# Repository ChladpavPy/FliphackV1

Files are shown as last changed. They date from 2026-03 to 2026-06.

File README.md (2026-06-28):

# Fliphack V1

A custom, pocket sized hardware multitool inspired by the Flipper Zero. Built to learn custom PCB design and integrate specific modules like GPS and long-range RF, including also the other Filpper Zero modules. Designed entirely from scratch in KiCad and Fusion 360.

## Project Features

* **Microcontroller:** ESP32-S3 WROOM 1U (16MB Flash, 8MB PSRAM) with external wifi antena
* **Display:** 1.69" IPS TFT LCD (ST7789 SPI)
* **Wireless and RF:** Sub-GHz (CC1101), 2.4GHz (nRF24L01+PA+LNA), NFC/RFID (PN532), and also external WIFI antena
* **Navigation:** GPS (NEO-8M)
* **Storage:** MicroSD Card module for SD card
* **Infrared:** High-power IR Transmitter (Vishay TSAL6400) and 38kHz IR Receiver
* **Controls:** 5-way navigation switch + SMT tactile buttons for BOOT and RST
* **Power:** External battery - 3.7V 800mAh, Size: 802540 (8x25x40mm) and USB C interface
* **Case:** Custom 3D modeled thick enclosure with snap-fit parts and M3 inserts

## Gallery

### Build Preview
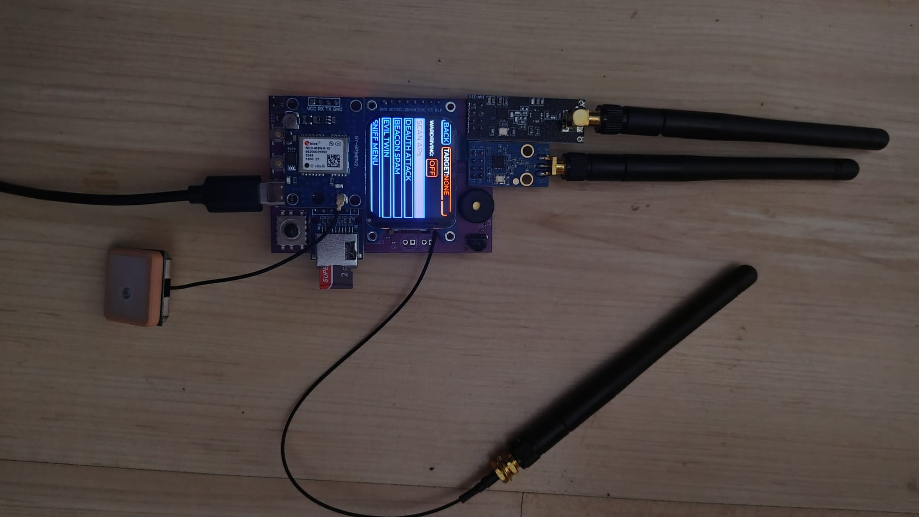
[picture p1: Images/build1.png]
Build Preview


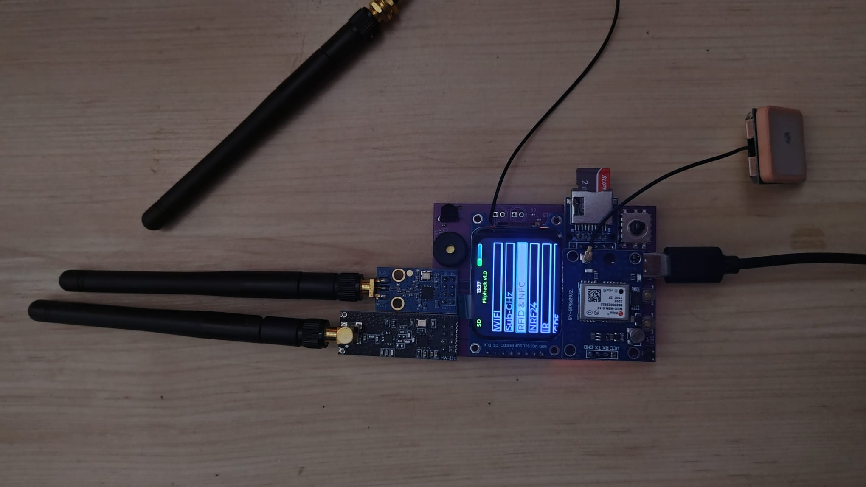
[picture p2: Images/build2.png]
Build Preview


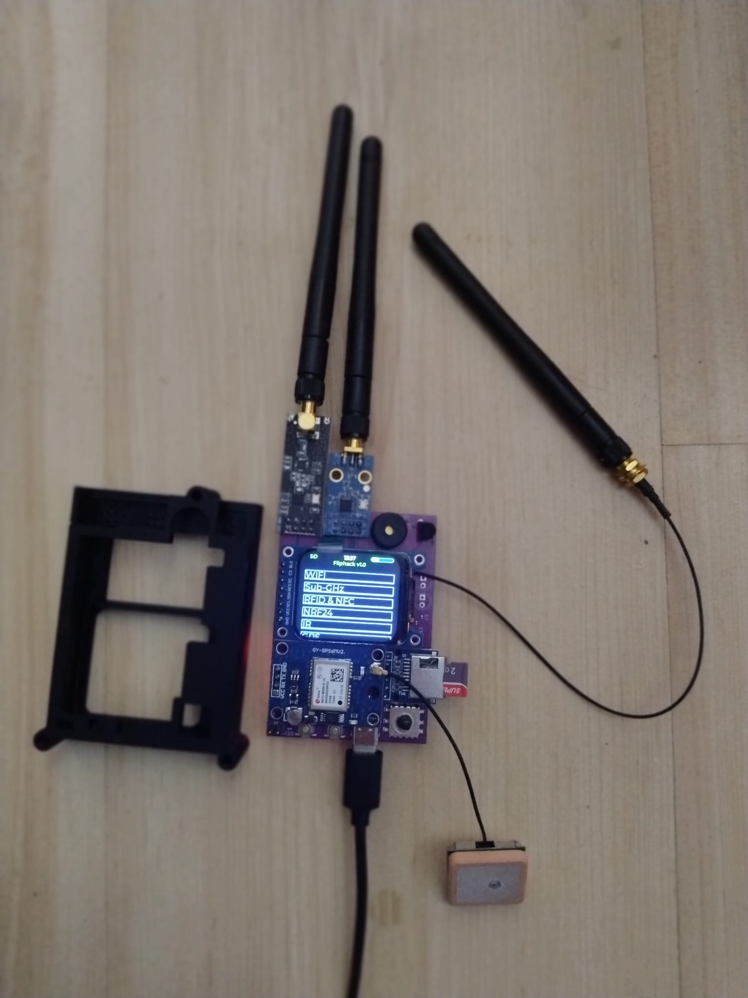
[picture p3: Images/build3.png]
Build Preview


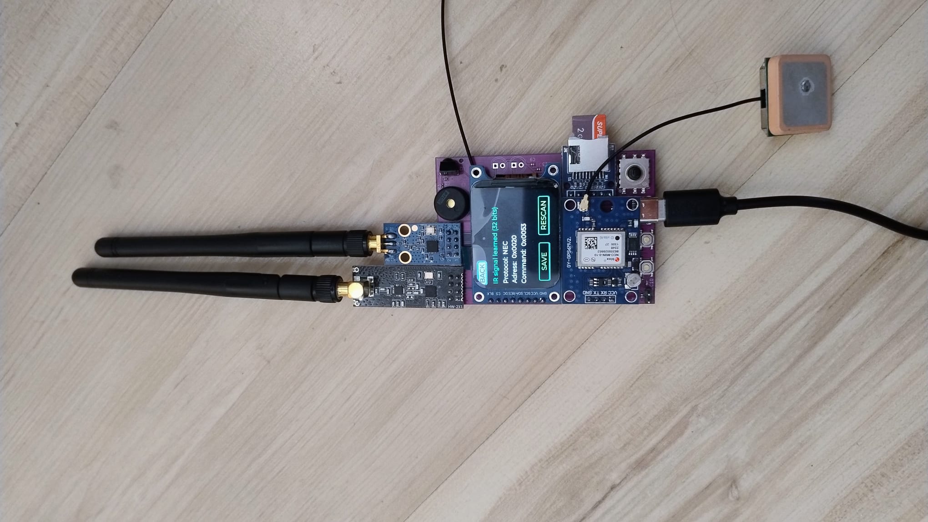
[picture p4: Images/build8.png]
Build Preview


### Assembly Preview
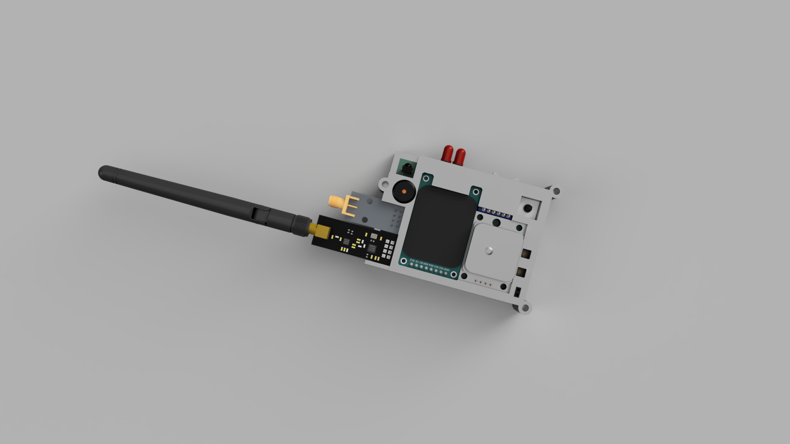
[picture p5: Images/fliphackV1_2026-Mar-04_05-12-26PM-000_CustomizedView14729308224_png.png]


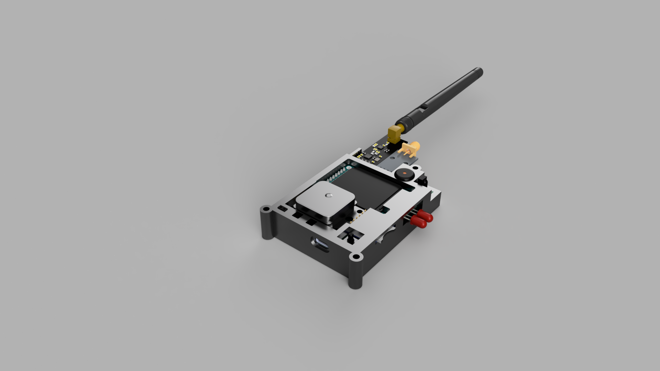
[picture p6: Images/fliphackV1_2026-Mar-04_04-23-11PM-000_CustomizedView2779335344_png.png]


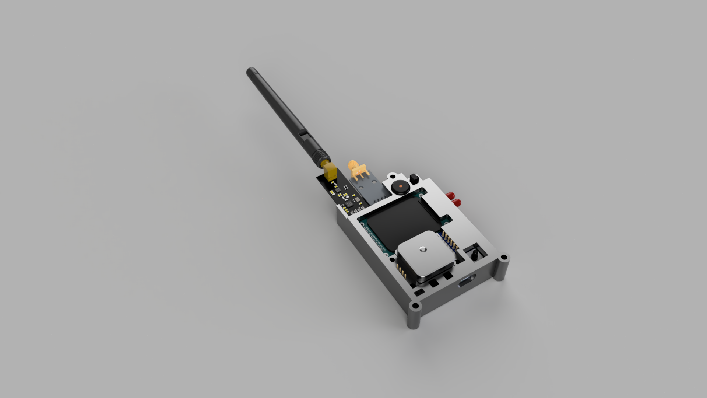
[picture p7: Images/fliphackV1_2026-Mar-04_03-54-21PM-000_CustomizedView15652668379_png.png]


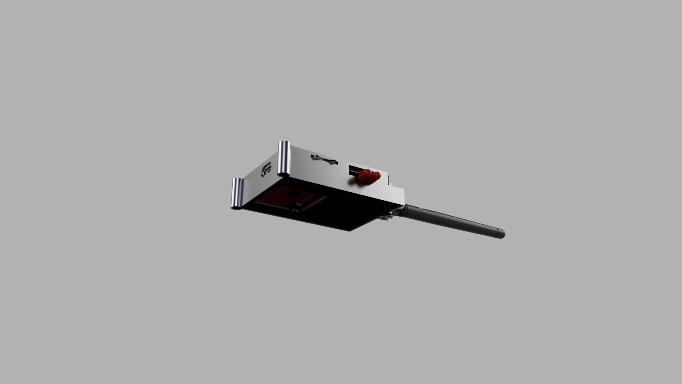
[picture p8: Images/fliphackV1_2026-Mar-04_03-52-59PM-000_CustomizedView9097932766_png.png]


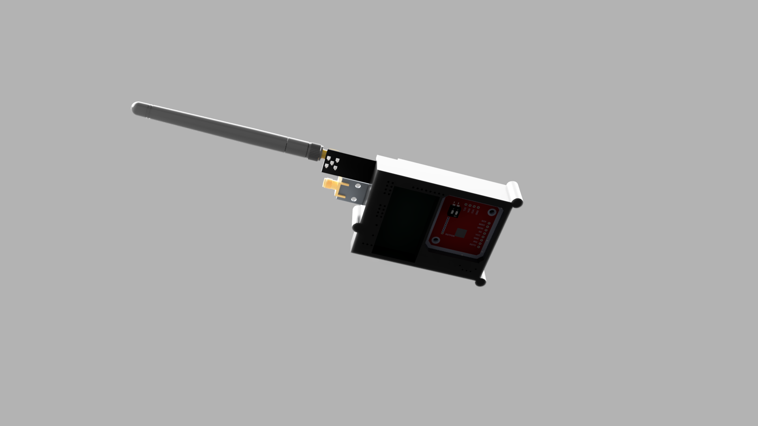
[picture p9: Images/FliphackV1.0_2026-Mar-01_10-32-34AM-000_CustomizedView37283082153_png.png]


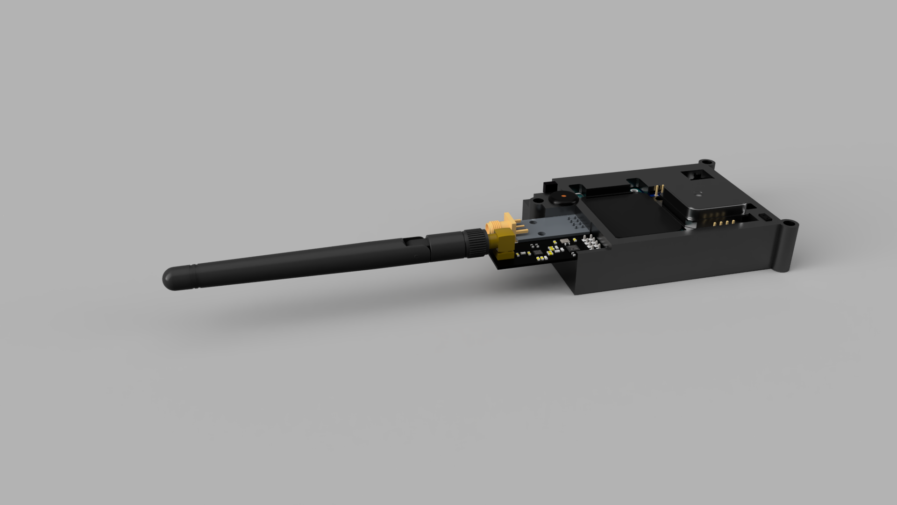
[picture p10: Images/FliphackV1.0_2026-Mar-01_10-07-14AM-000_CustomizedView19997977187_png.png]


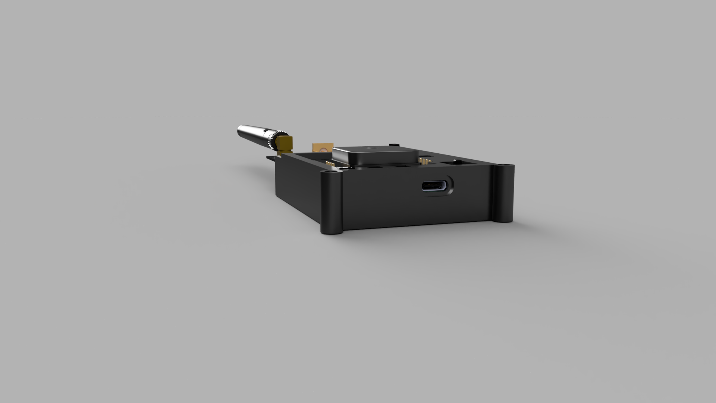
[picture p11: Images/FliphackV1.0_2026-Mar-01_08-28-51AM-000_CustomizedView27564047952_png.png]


### 3D PCB Render
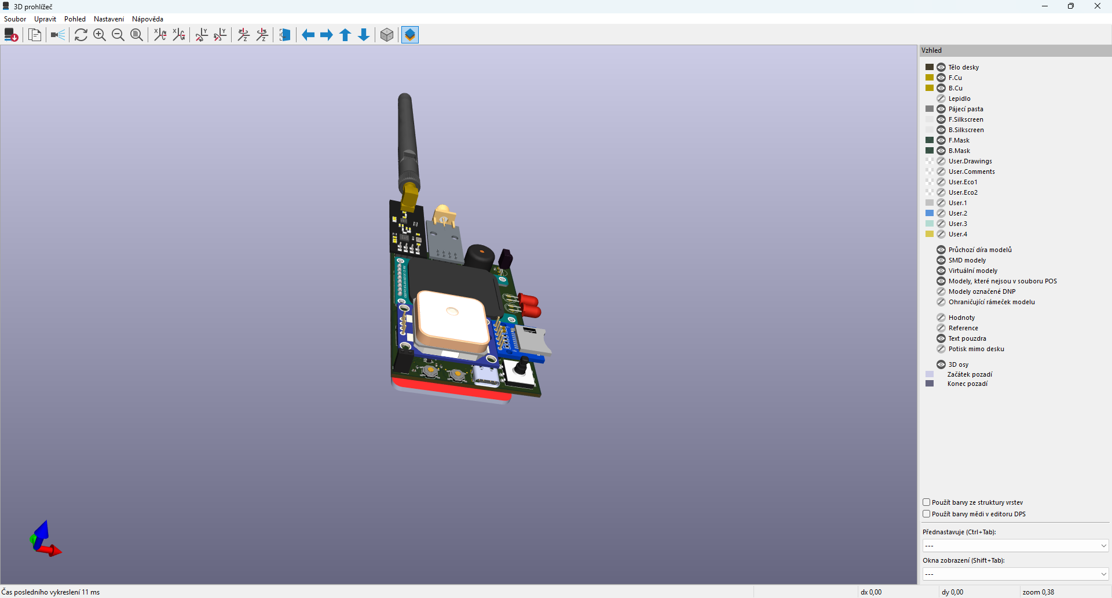
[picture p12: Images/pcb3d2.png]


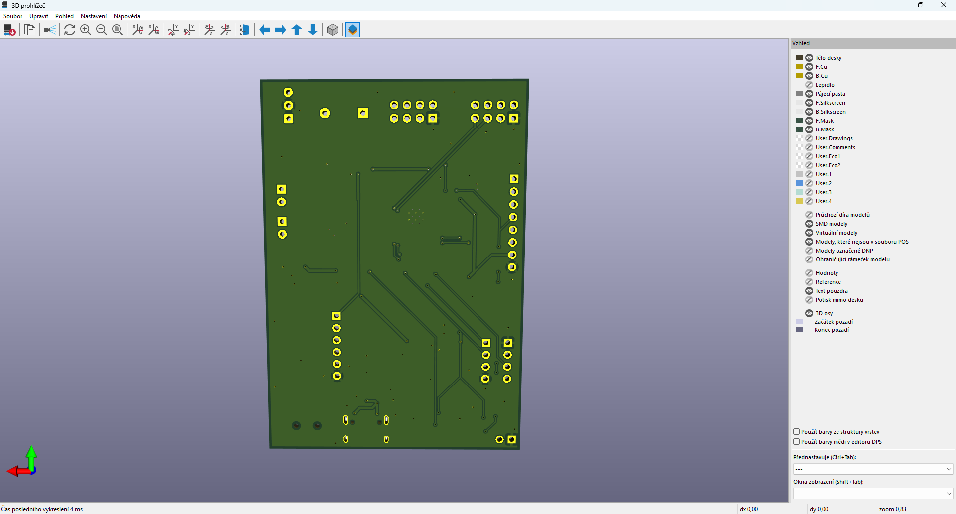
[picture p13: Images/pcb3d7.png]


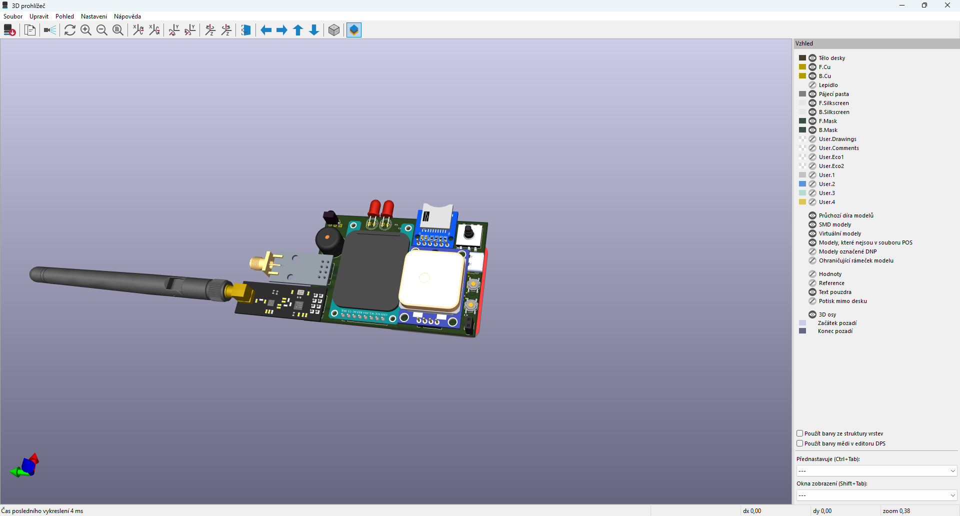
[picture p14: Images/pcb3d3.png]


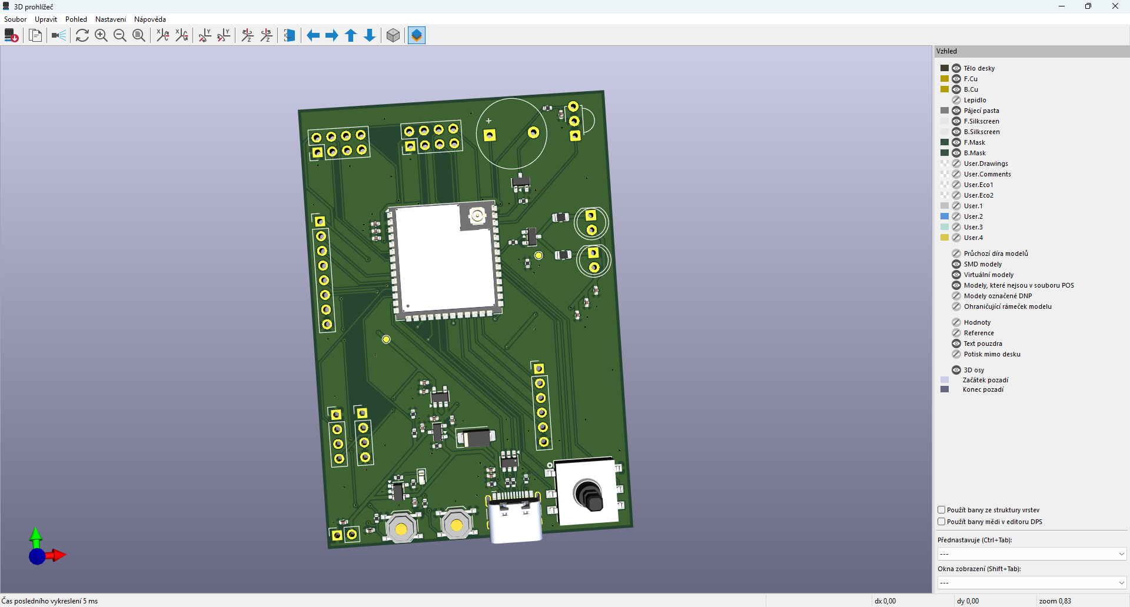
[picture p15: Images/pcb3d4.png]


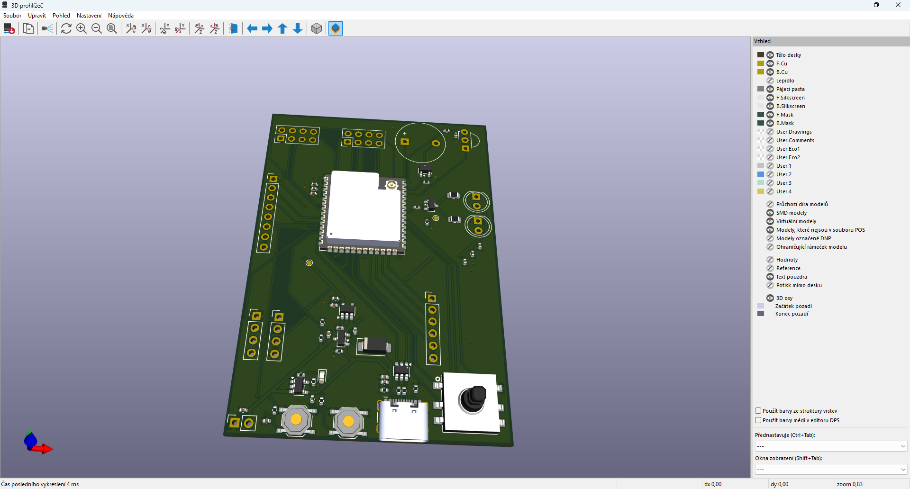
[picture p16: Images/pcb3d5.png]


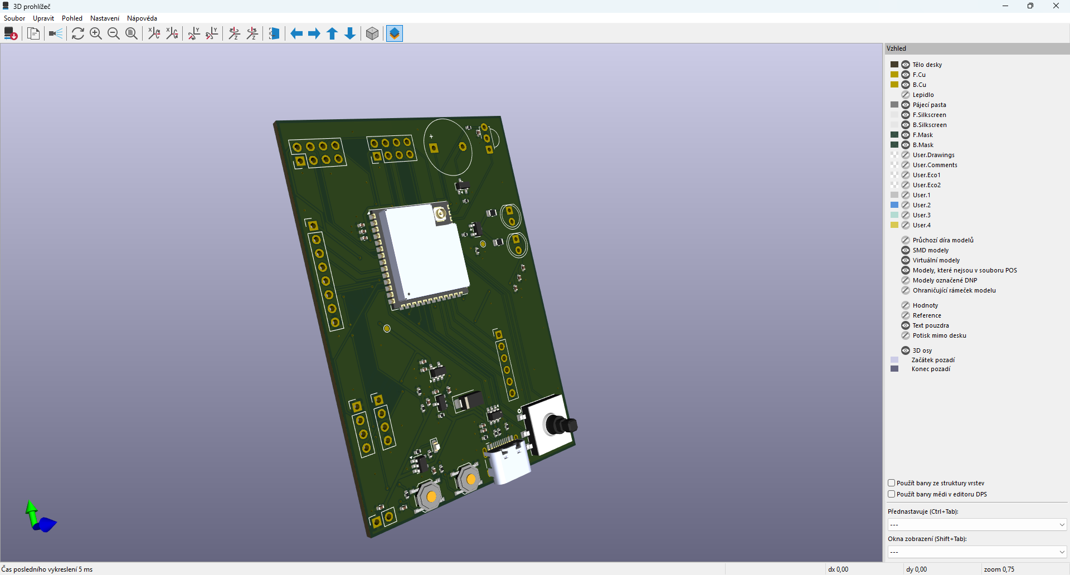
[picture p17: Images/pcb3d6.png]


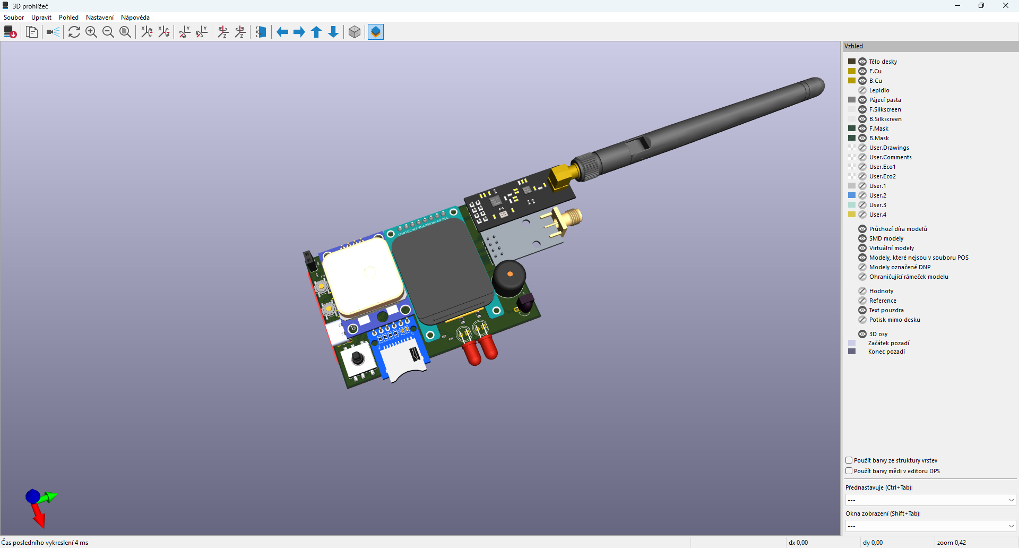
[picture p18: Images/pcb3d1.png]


### PCB Routing
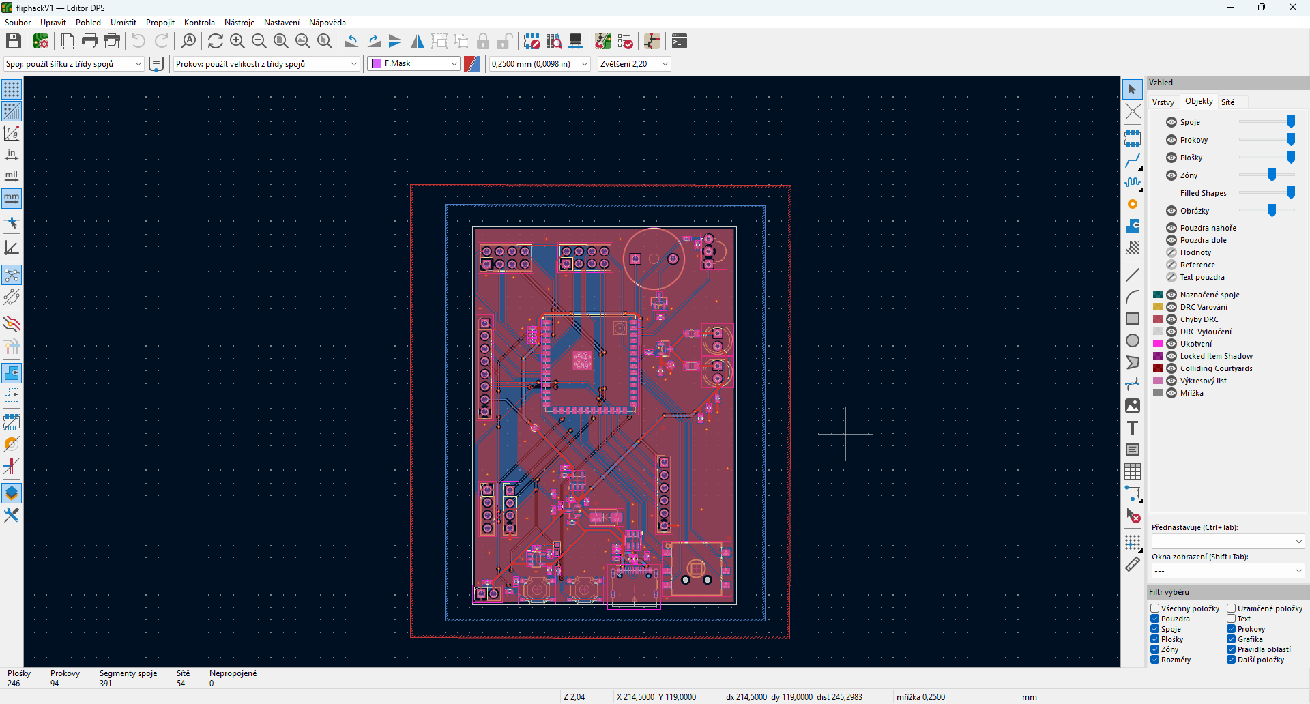
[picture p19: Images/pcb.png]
PCB 2D


### Schematic
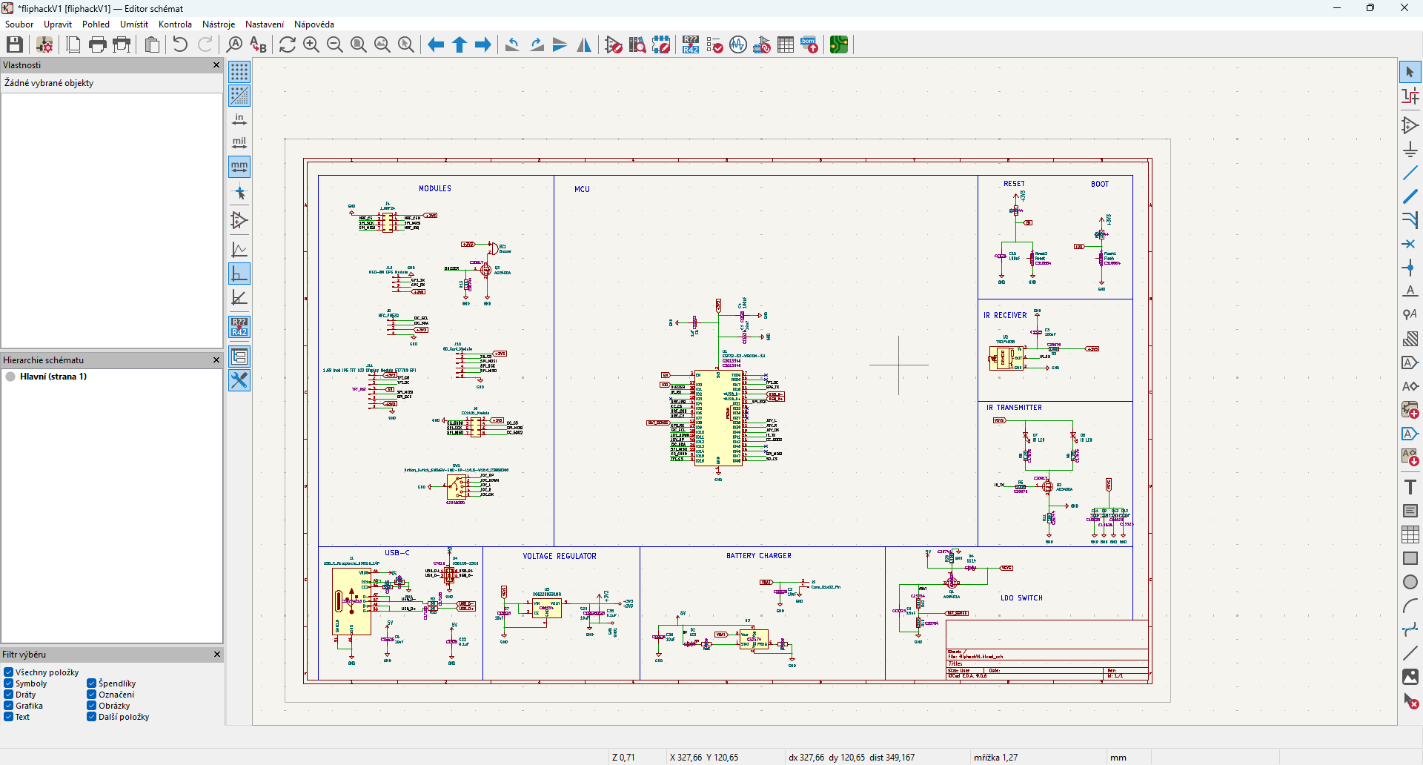
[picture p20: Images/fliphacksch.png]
Schematic


---

## Bill of Materials (BOM)

| Component | Qty | Description | LCSC Part # / Note |
| :--- | :---: | :--- | :--- |
| **ESP32-S3-WROOM-1U** | 5 | MCU (16MB Flash, 8MB PSRAM, U.FL connector) | N16R8 Version - This is a problem, I wanted to ship it assembled with the pcb from jlcpcb, but unfortunately it must be ordered with standard pcb, that means that the price would rise from approximately 33 USD to crazy over 100 USD - So my plan is to order it from LCSC.com and ship it with the LCSC parts in the same box, because they support it, I think -  https://www.lcsc.com/product-detail/C3013946.html?s_z=n_esp32-s3-wroom-1u / or there is the LCSC part number - C3013946|
| **2.4GHz Antenna** + Pigtail | 1 |3dBi WiFi Antenna with 17cm U.FL IPX to SMA cable	Essential for ESP32-S3-1U -| https://a.aliexpress.com/_EItoDMg | 
| **1.69" SPI Display** | 1 | LCD with ST7789 driver (240x280px) | SPI Interface https://a.aliexpress.com/_EIgOvRA| 
| **CC1101 Module** | 1 | Sub-GHz RF module (with SMA antenna) | E07-M1101D https://a.aliexpress.com/_Ey9DMVW |
| **nRF24L01+PA+LNA Module** | 1 | 2.4GHz RF module (Mouse Hijacking) | https://a.aliexpress.com/_Ew8TYLa  |
| **PN532 Module** | 1 | NFC/RFID 13.56MHz module | https://a.aliexpress.com/_ExXcsbE |
| **Neo-8M GPS Module** | 1 | GPS module with ceramic patch antenna | https://a.aliexpress.com/_EvsK2kc |
| **MicroSD Card Module** | 1 | For offline data logging | https://a.aliexpress.com/_EHdpg1A |
| **TSOP4838** | 10 | 38kHz Infrared Receiver | https://a.aliexpress.com/_EzLWQ5W |
| **Vishay TSAL6400** | 10 | 5mm 940nm THT Infrared LEDs (High power)|https://a.aliexpress.com/_EIPCbXW| | **Passive Piezzo Buzzer** | 1 | 12x9.5mm, RM7.6 OR smaller diameter, just make sure that the pins diameter is ok, otherwise you would have to add more solder
| **Passive Piezzo Buzzer** | 10 | diameter size 12 * 9.5 or smaller |https://a.aliexpress.com/_ExtD1xe|
| **TS-1187A Buttons** | 10 | SMT Tactile Switches (3x6mm footprint) | **C318884** (Basic Part - included in JLCPCB assembly) |
| **LiPo Battery** | 1 | 3.7V 800mAh, Size: 802540 (8x25x40mm) |https://a.aliexpress.com/_EQnfApW |

### Mechanical & Assembly
| Item | Qty | Specification | Purpose |
| :--- | :---: | :--- | :--- |
| **M3 Heat-set Inserts** | 4 | Brass inserts (M3x3x4.2mm) | Case mounting |
| **M3 Screws** | 4 | M3x6mm (Button Head) | Enclosure assembly |
| **3D Printed Case** | 1 | Custom PLA/PETG Enclosure | Files in `3D_Models` |

---

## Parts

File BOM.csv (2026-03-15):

Reference | Qty | Value | DNP | Exclude from BOM | Exclude from Board | Footprint | Datasheet | MNF PART NUMBER | LCSC
BZ1 | 1 | Buzzer |  |  |  | Buzzer_Beeper:Buzzer_12x9.5RM7.6 | ~
C1,C2,C6,C7,C8,C9,C11,C12,C13,C20,C36 | 11 | 10uF |  |  |  | Capacitor_SMD:C_0402_1005Metric | ~ | C15525 | C15525
C3,C4,C10 | 3 | 100nF |  |  |  | Capacitor_SMD:C_0402_1005Metric | ~ | C1525 | C1525
C5 | 1 | 1uF |  |  |  | Capacitor_SMD:C_0402_1005Metric | ~ | C52923 | C52923
C22,C35 | 2 | 0.1uF |  |  |  | Capacitor_SMD:C_0402_1005Metric | ~ | C1525 | C1525
D1 | 1 | LED |  |  |  | LED_SMD:LED_0603_1608Metric | ~ | C2286 | C2286
D4 | 1 | SS14 |  |  |  | Diode_SMD:D_SMA | https://www.vishay.com/docs/88746/ss12.pdf | C2480 | C2480
D7,D8 | 2 | IR LED |  |  |  | LED_THT:LED_D5.0mm | ~
Flash1 | 1 | Flash |  |  |  | Button_Switch_SMD:SW_Push_1P1T_XKB_TS-1187A | ~ | C318884 | C318884
J1 | 1 | USB_C_Receptacle_USB2.0_14P |  |  |  | Connector_USB:USB_C_Receptacle_HCTL_HC-TYPE-C-16P-01A | https://www.usb.org/sites/default/files/documents/usb_type-c.zip | C19274016 | C19274016
J2 | 1 | Conn_01x02_Pin |  |  |  | Connector_PinSocket_2.54mm:PinSocket_1x02_P2.54mm_Vertical | ~
J4 | 1 | J_NRF24 |  |  |  | Connector_PinHeader_2.54mm:PinHeader_2x04_P2.54mm_Vertical | ~
J6 | 1 | CC1101_Module |  |  |  | Connector_PinHeader_2.54mm:PinHeader_2x04_P2.54mm_Vertical | ~
J9 | 1 | NFC_PN532 |  |  |  | Connector_PinHeader_2.54mm:PinHeader_1x04_P2.54mm_Vertical | ~
J10 | 1 | SD_Card_Module |  |  |  | Connector_PinHeader_2.54mm:PinHeader_1x06_P2.54mm_Vertical | ~
J11 | 1 | 1.69 inch IPS TFT LCD Display Module ST7789 SPI |  |  |  | Connector_PinHeader_2.54mm:PinHeader_1x08_P2.54mm_Vertical | ~
J12 | 1 | NEO-8M GPS Module |  |  |  | Connector_PinHeader_2.54mm:PinHeader_1x04_P2.54mm_Vertical | ~
Q1 | 1 | AO3401A |  |  |  | Package_TO_SOT_SMD:SOT-23 | http://www.aosmd.com/pdfs/datasheet/AO3401A.pdf | C15127 | C15127
Q2,Q3 | 2 | AO3400A |  |  |  | Package_TO_SOT_SMD:SOT-23 | ~ | C20917 | C20917
R1,R15 | 2 | 2K |  |  |  | Resistor_SMD:R_0402_1005Metric | ~ | C4109 | C4109
R2,R18 | 2 | 0R |  |  |  | Resistor_SMD:R_0402_1005Metric | ~ | C17168 | C17168
R3,R5 | 2 | 100R |  |  |  | Resistor_SMD:R_0402_1005Metric | ~ | C25076 | C25076
R4,R11,R13,R21 | 4 | 10K |  |  |  | Resistor_SMD:R_0402_1005Metric | ~ | C25744 | C25744
R8,R9 | 2 | 4.7R |  |  |  | Resistor_SMD:R_0805_2012Metric | ~ | C17675 | C17675
R12,R19 | 2 | 200K |  |  |  | Resistor_SMD:R_0402_1005Metric | ~ | C25764 | C25764
R14,R17 | 2 | 5.1K |  |  |  | Resistor_SMD:R_0402_1005Metric | ~ | C25905 | C25905
R20 | 1 | 100K |  |  |  | Resistor_SMD:R_0402_1005Metric | ~ | C25741 | C25741
Reset2 | 1 | Reset |  |  |  | Button_Switch_SMD:SW_Push_1P1T_XKB_TS-1187A | ~ | C318884 | C318884
SW1 | 1 | Button_Switch_SMD:SW-SMD-6P-L10.5-W10.0_C2858290 |  |  |  | Button_Switch_SMD:SW-SMD-6P-L10.5-W10.0_C2858290 |  | C2858290 | C2858290
U1 | 1 | ESP32-S3-WROOM-1U |  |  |  | RF_Module:ESP32-S3-WROOM-1U | https://www.espressif.com/sites/default/files/documentation/esp32-s3-wroom-1_wroom-1u_datasheet_en.pdf | C3013946 | C3013946
U2 | 1 | TSOP4838 |  |  |  | OptoDevice:Vishay_MINICAST-3Pin | http://www.vishay.com/docs/82491/tsop382.pdf
U3 | 1 | MCP73831-2-OT |  |  |  | Package_TO_SOT_SMD:SOT-23-5 | http://ww1.microchip.com/downloads/en/DeviceDoc/20001984g.pdf | C32574 | C32574
U4 | 1 | USBLC6-2SC6 |  |  |  | Package_TO_SOT_SMD:SOT-23-6 | https://www.st.com/resource/en/datasheet/usblc6-2.pdf | C7519 | C7519
U5 | 1 | XC6220B331MR |  |  |  | Package_TO_SOT_SMD:SOT-23-5 | https://www.torexsemi.com/file/xc6220/XC6220.pdf | C86534 | C86534

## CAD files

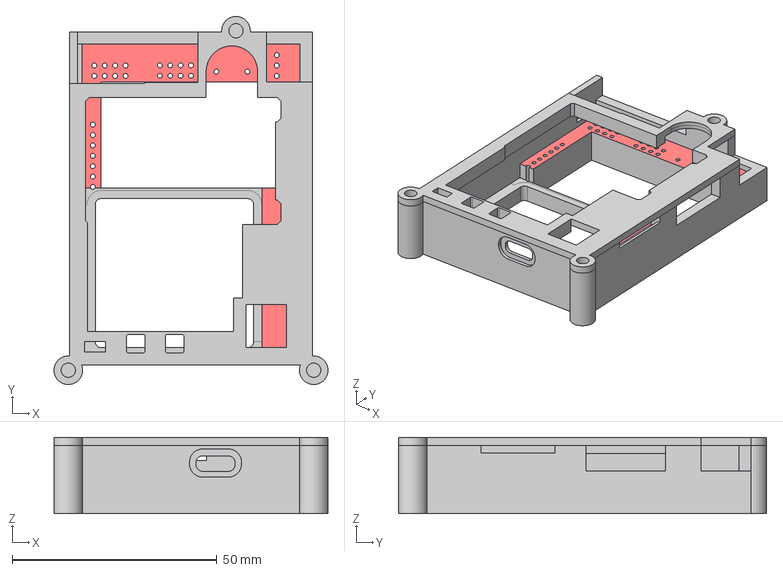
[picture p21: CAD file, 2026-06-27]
3D_Models/Fliphack_V1_0.3.step
67.0 x 90.0 x 18.7 mm

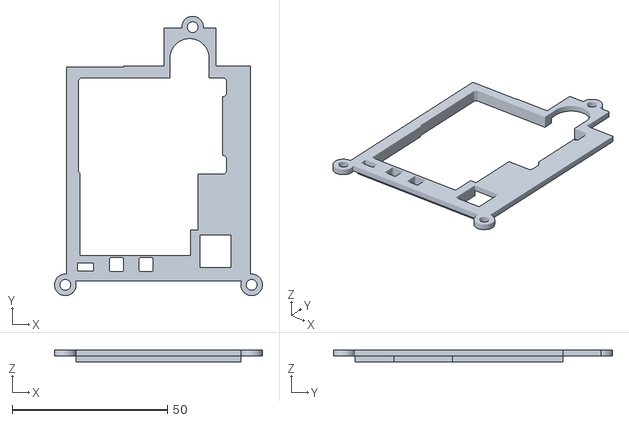
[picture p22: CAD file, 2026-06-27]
3D_Models/Body_top_repair1.stl
67.0 x 90.0 x 4.00

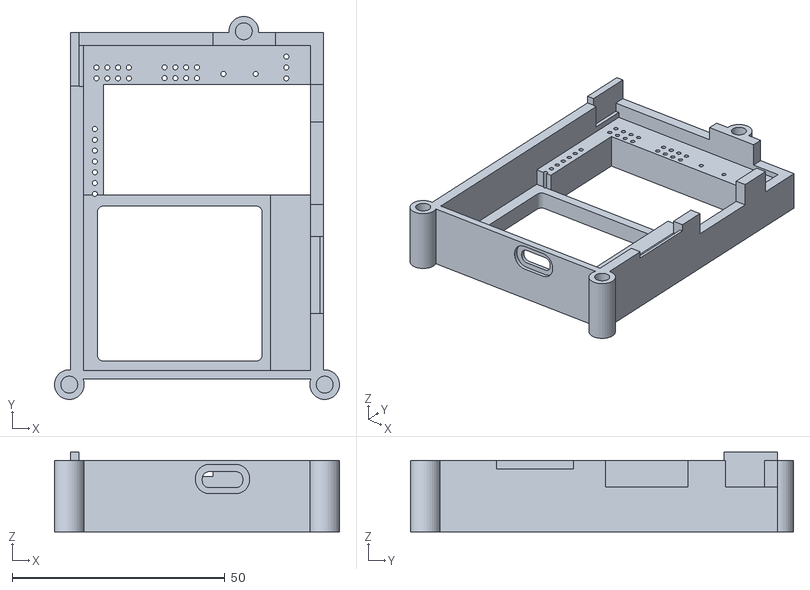
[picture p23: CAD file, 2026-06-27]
3D_Models/Body_bottom_repair1.stl
67.0 x 90.0 x 18.7

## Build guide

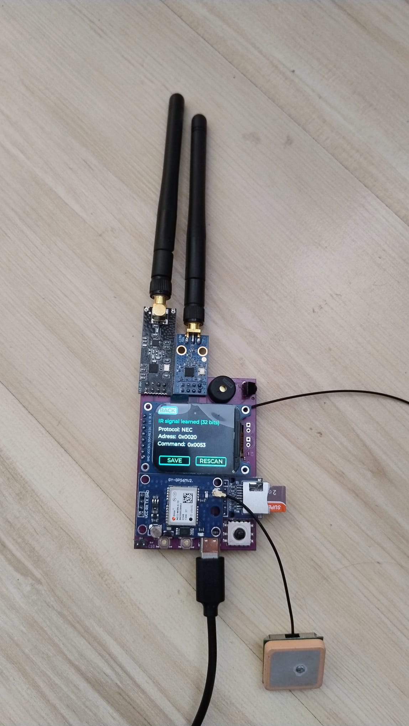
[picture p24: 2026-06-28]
Images/build6.jpg

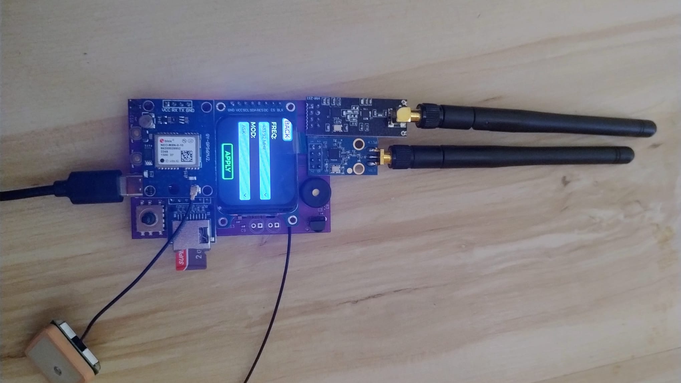
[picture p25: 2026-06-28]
Images/build4.jpg

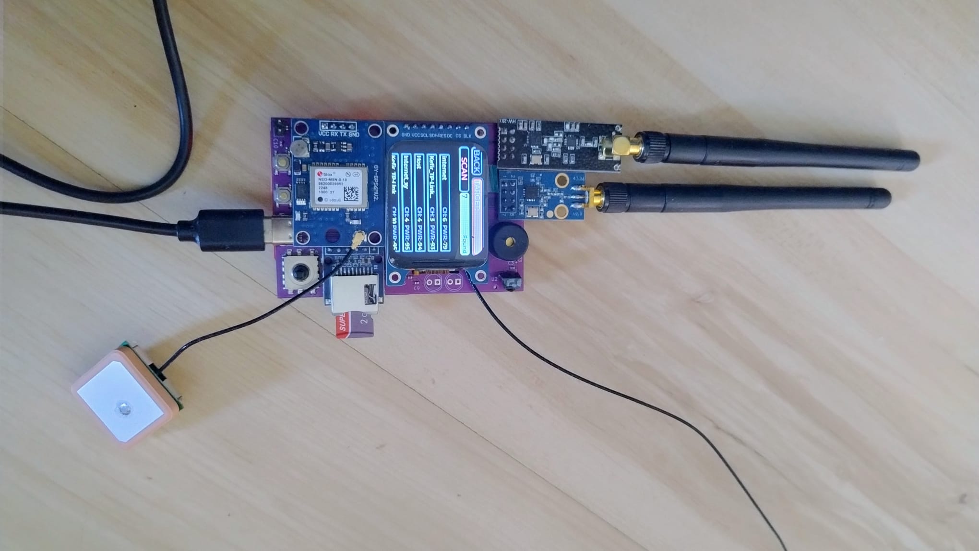
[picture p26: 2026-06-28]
Images/build7.jpg

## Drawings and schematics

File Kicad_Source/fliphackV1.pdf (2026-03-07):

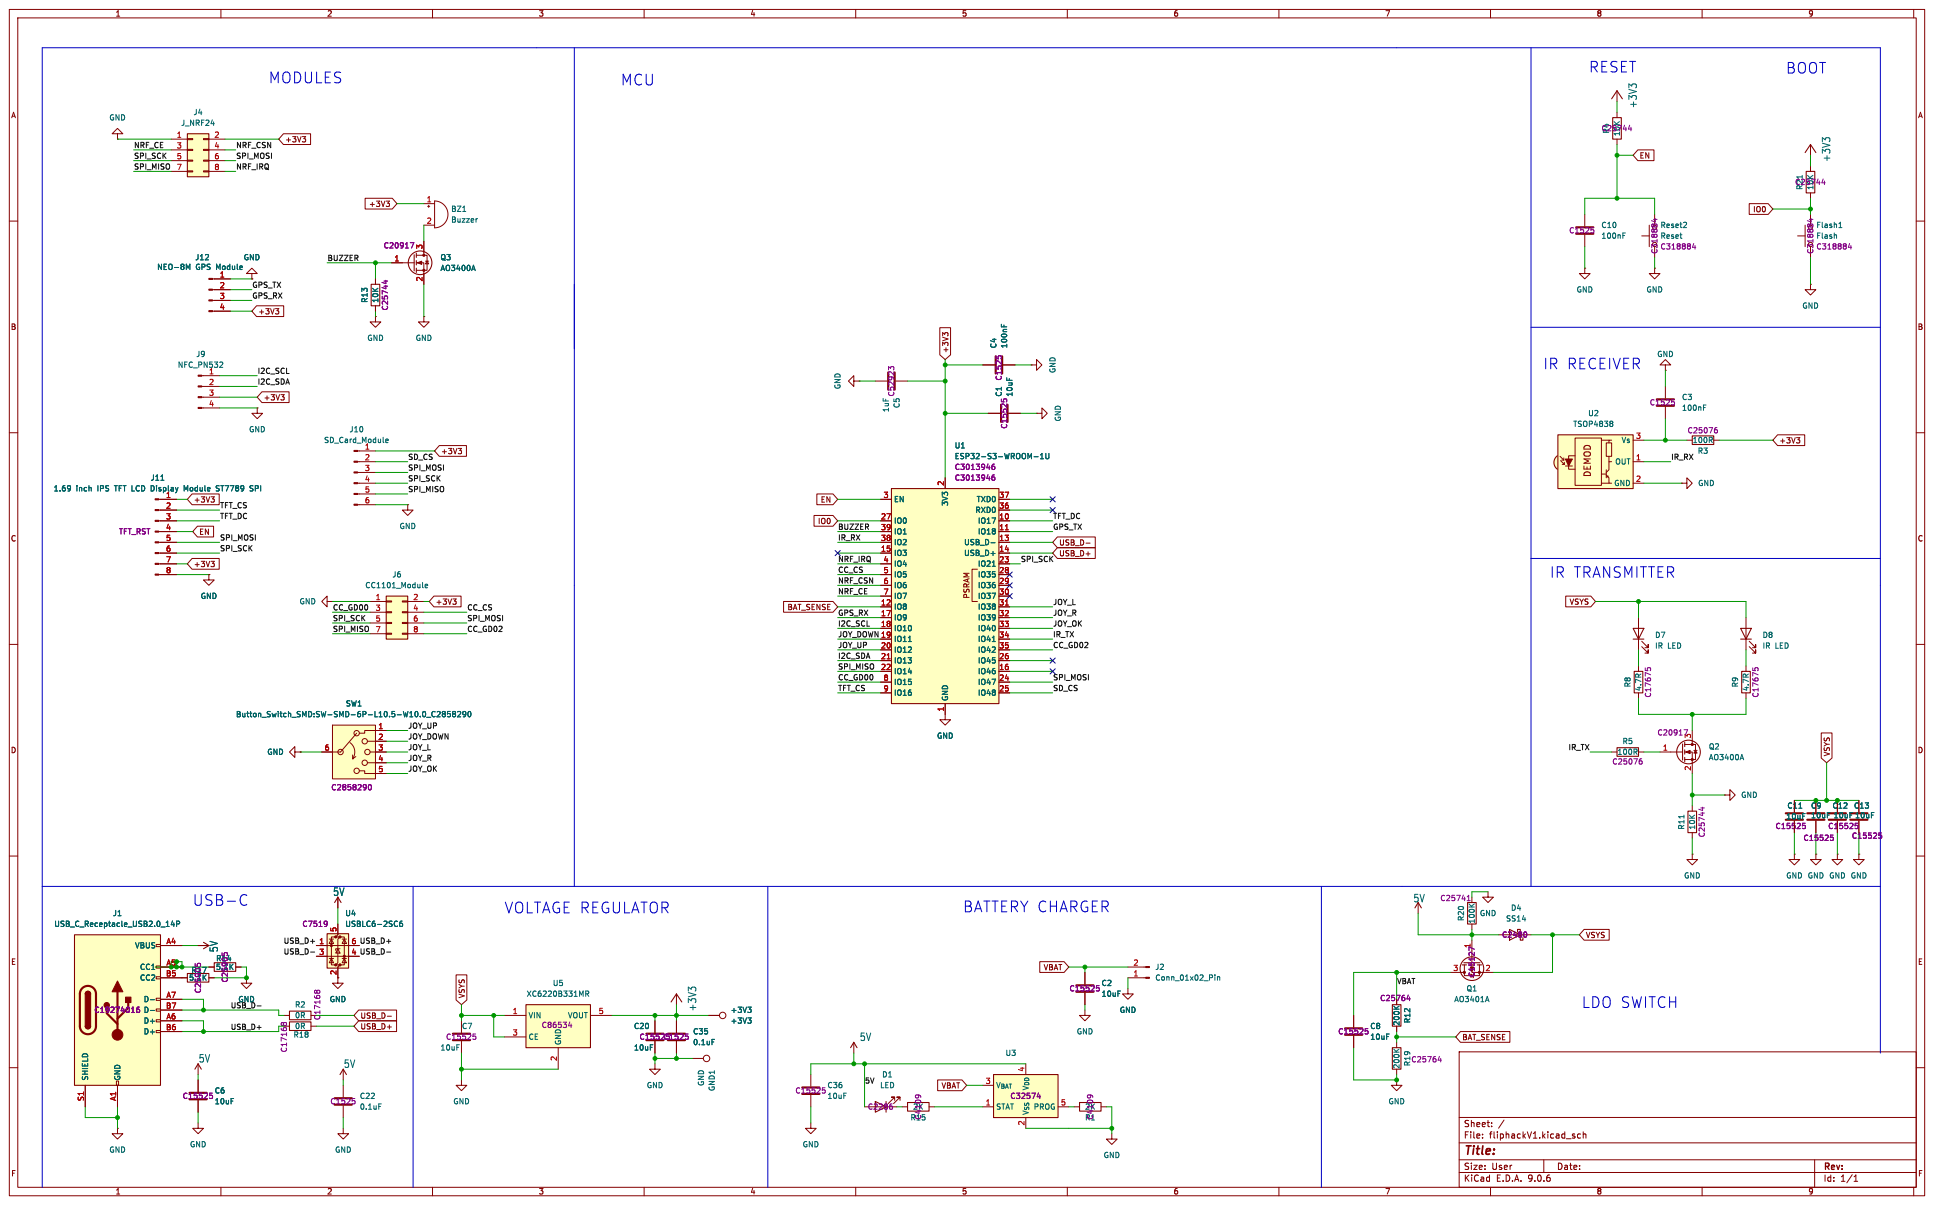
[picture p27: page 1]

J9 NFC_PN532 GND
J12 NEO-8M GPS Module GND

1.69 inch IPS TFT LCD Display Module ST7789 SPI TFT_RST

Id: 1/1 Title: File: fliphackV1.kicad_sch Sheet: /

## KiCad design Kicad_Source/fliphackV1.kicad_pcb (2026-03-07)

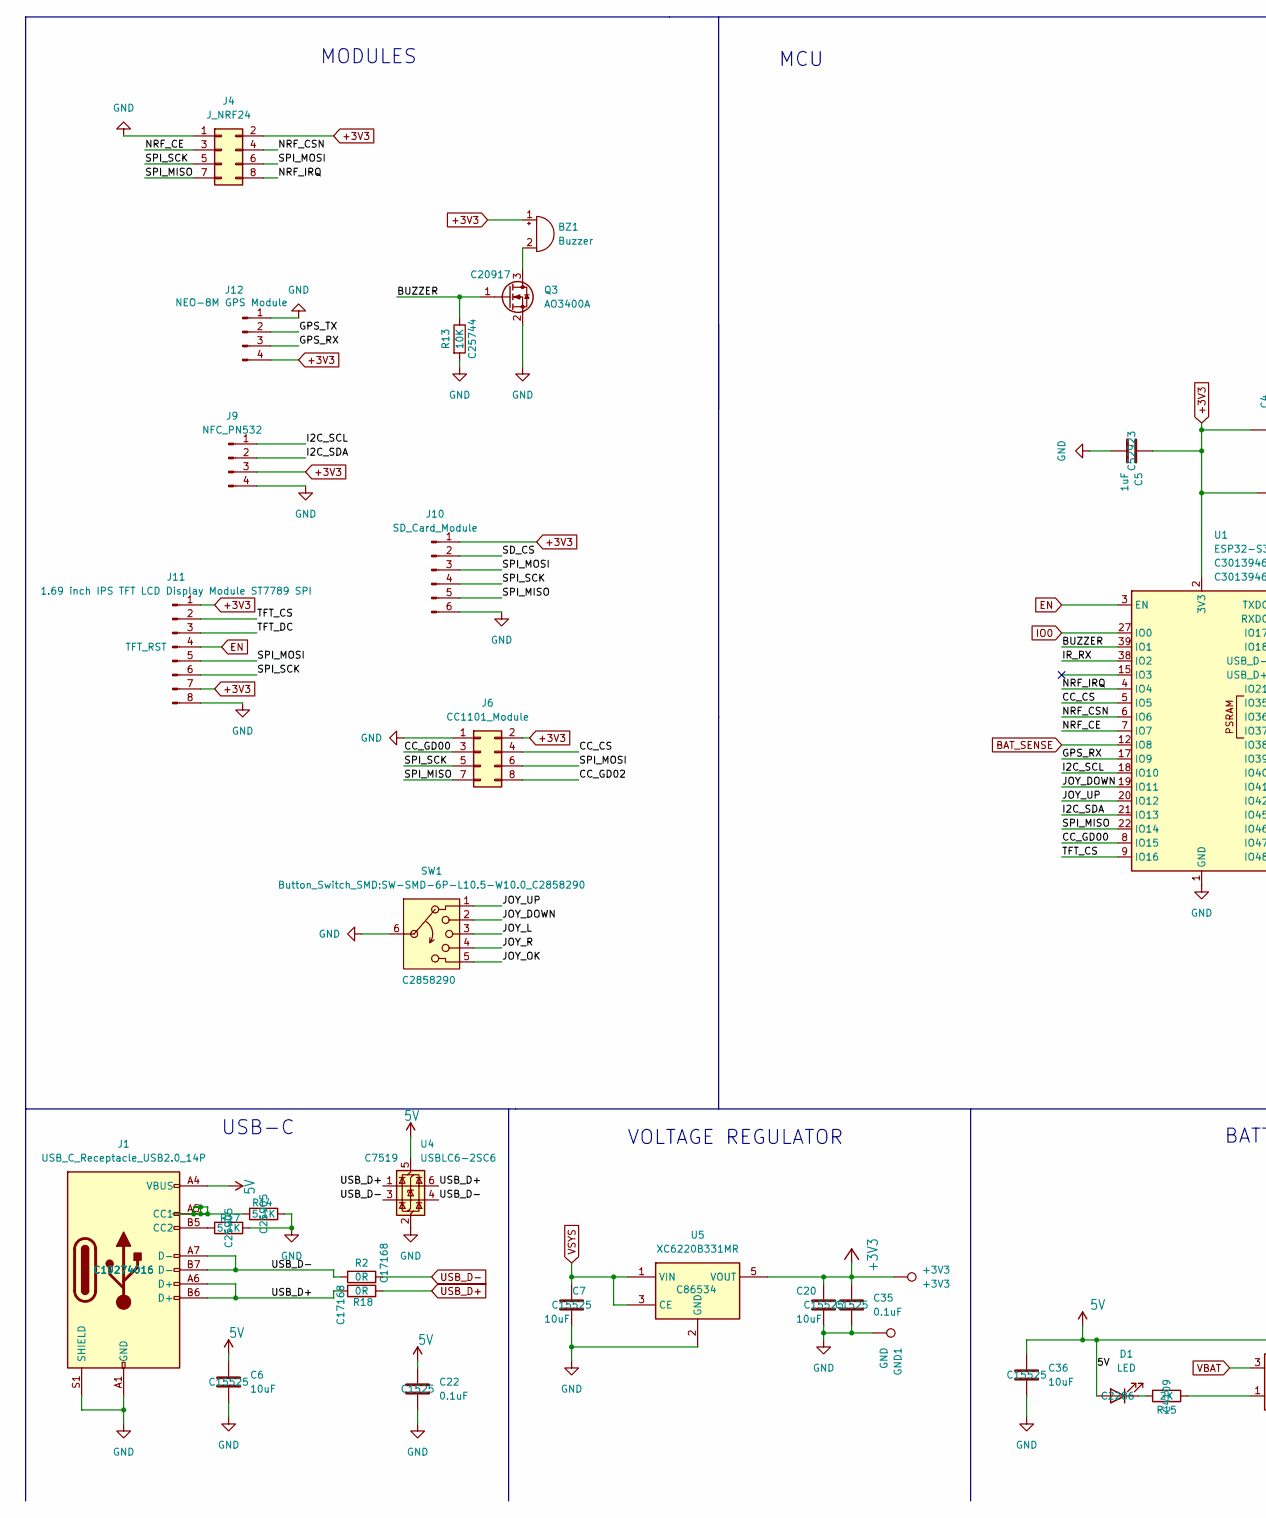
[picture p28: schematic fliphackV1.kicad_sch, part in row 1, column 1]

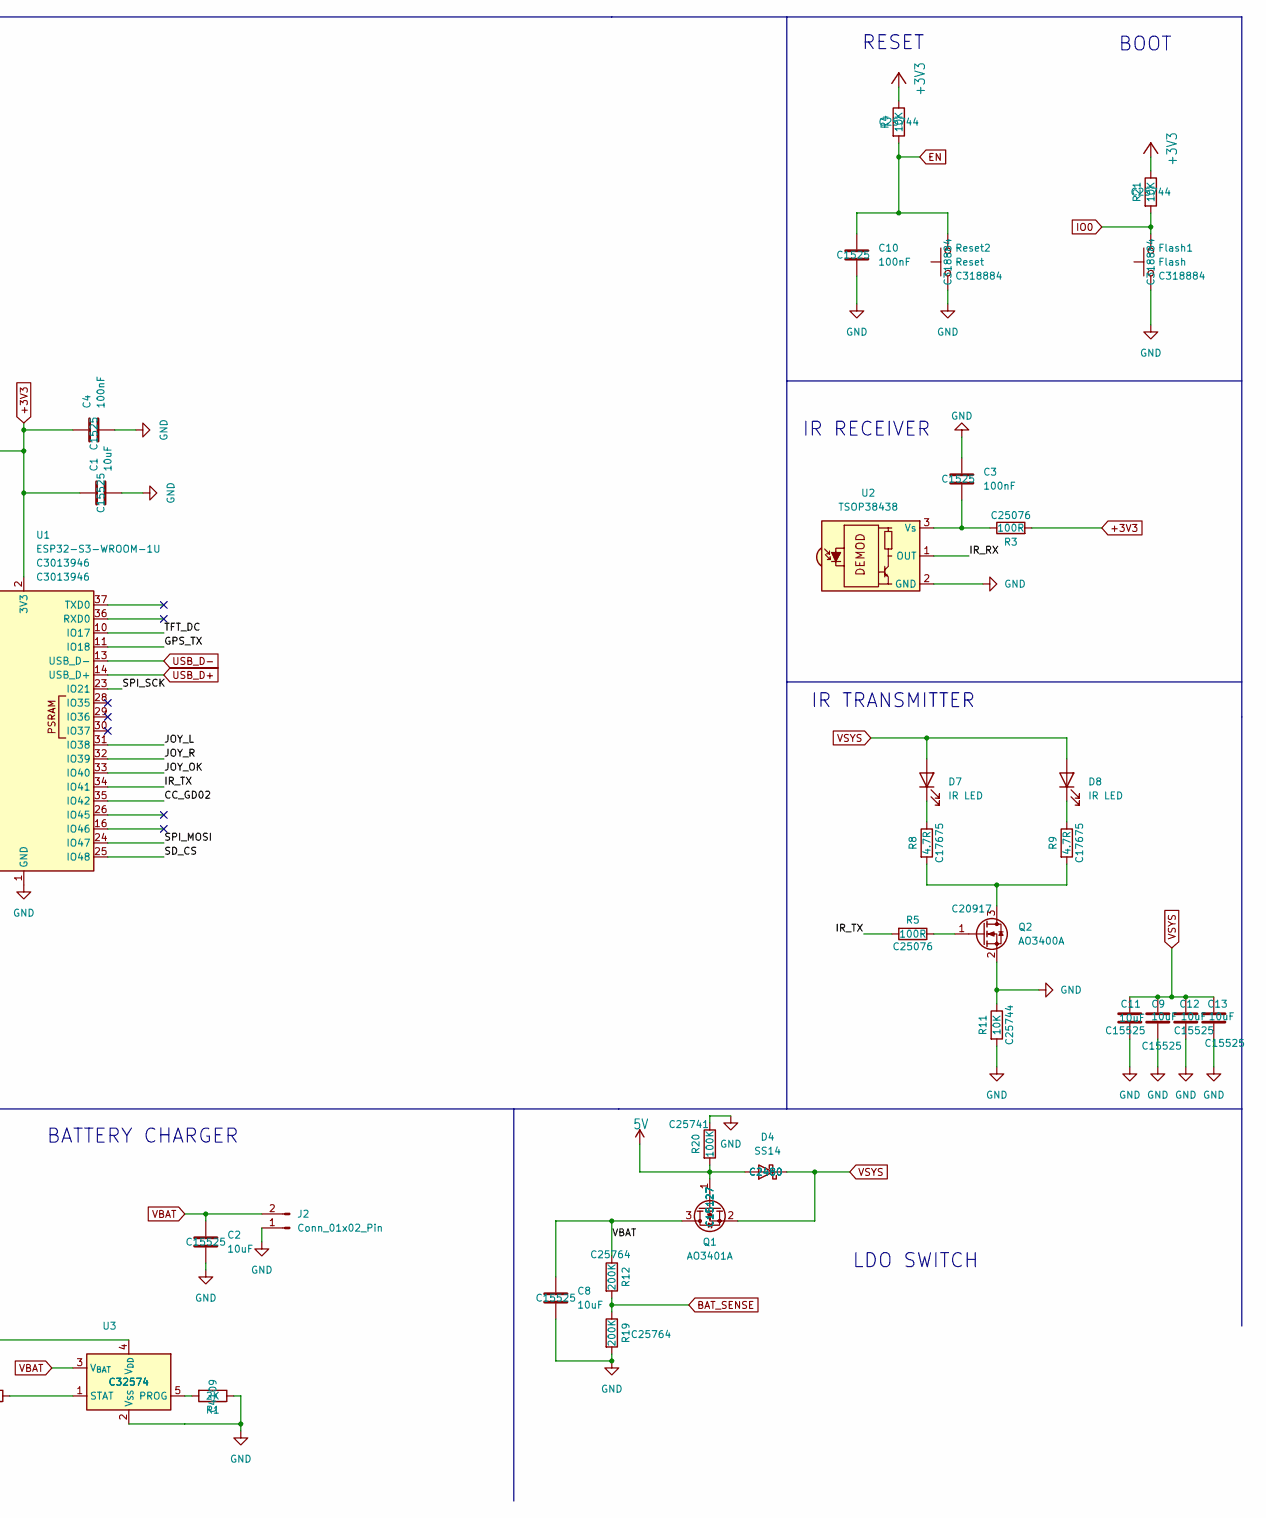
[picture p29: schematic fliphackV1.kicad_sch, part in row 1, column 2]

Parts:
+3V3: +3V3; TestPoint_Pad_D1.0mm
BZ1: Buzzer; Buzzer_12x9.5RM7.6
C1, C2, C6, C7, C8, C9, C11, C12, C13, C20, C36: 10uF; C_0402_1005Metric; MNF PART NUMBER C15525; LCSC C15525
C3, C4, C10: 100nF; C_0402_1005Metric; MNF PART NUMBER C1525; LCSC C1525
C5: 1uF; C_0402_1005Metric; MNF PART NUMBER C52923; LCSC C52923
C22, C35: 0.1uF; C_0402_1005Metric; MNF PART NUMBER C1525; LCSC C1525
D1: LED; LED_0603_1608Metric; MNF PART NUMBER C2286; LCSC C2286
D4: SS14; D_SMA; MNF PART NUMBER C2480; LCSC C2480
D7, D8: IR LED; LED_D5.0mm
Flash1: Flash; SW_Push_1P1T_XKB_TS-1187A; MNF PART NUMBER C318884; LCSC C318884
GND1: GND; TestPoint_Pad_D1.0mm
J1: USB_C_Receptacle_USB2.0_14P; USB_C_Receptacle_HCTL_HC-TYPE-C-16P-01A; MNF PART NUMBER C19274016; LCSC C19274016
J2: Conn_01x02_Pin; PinSocket_1x02_P2.54mm_Vertical
J4: J_NRF24; PinHeader_2x04_P2.54mm_Vertical
J6: CC1101_Module; PinHeader_2x04_P2.54mm_Vertical
J9: NFC_PN532; PinHeader_1x04_P2.54mm_Vertical
J10: SD_Card_Module; PinHeader_1x06_P2.54mm_Vertical
J11: 1.69 inch IPS TFT LCD Display Module ST7789 SPI; PinHeader_1x08_P2.54mm_Vertical
J12: NEO-8M GPS Module; PinHeader_1x04_P2.54mm_Vertical
Q1: AO3401A; SOT-23; MNF PART NUMBER C15127; LCSC C15127
Q2, Q3: AO3400A; SOT-23; MNF PART NUMBER C20917; LCSC C20917
R1, R15: 2K; R_0402_1005Metric; MNF PART NUMBER C4109; LCSC C4109
R2, R18: 0R; R_0402_1005Metric; MNF PART NUMBER C17168; LCSC C17168
R3, R5: 100R; R_0402_1005Metric; MNF PART NUMBER C25076; LCSC C25076
R4, R11, R13, R21: 10K; R_0402_1005Metric; MNF PART NUMBER C25744; LCSC C25744
R8, R9: 4.7R; R_0805_2012Metric; MNF PART NUMBER C17675; LCSC C17675
R12, R19: 200K; R_0402_1005Metric; MNF PART NUMBER C25764; LCSC C25764
R14, R17: 5.1K; R_0402_1005Metric; MNF PART NUMBER C25905; LCSC C25905
R20: 100K; R_0402_1005Metric; MNF PART NUMBER C25741; LCSC C25741
Reset2: Reset; SW_Push_1P1T_XKB_TS-1187A; MNF PART NUMBER C318884; LCSC C318884
SW1: Button_Switch_SMD:SW-SMD-6P-L10.5-W10.0_C2858290; SW-SMD-6P-L10.5-W10.0_C2858290; MNF PART NUMBER C2858290; LCSC C2858290
U1: ESP32-S3-WROOM-1U; MNF PART NUMBER C3013946; LCSC C3013946
U2: TSOP38438; Vishay_MINICAST-3Pin
U3: MCP73831-2-OT; SOT-23-5; MNF PART NUMBER C32574; LCSC C32574
U4: USBLC6-2SC6; SOT-23-6; MNF PART NUMBER C7519; LCSC C7519
U5: XC6220B331MR; SOT-23-5; MNF PART NUMBER C86534; LCSC C86534

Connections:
5V: C6.1, C22.1, C36.1, D1.2 (A), D4.2 (A), J1.A4 (VBUS), J1.A9 (VBUS), J1.B4 (VBUS), J1.B9 (VBUS), Q1.1 (G), R20.2, U3.4 (V_{DD}), U4.5 (VBUS)
+3V3: +3V3.1, BZ1.1 (+), C1.1, C4.1, C5.1, C20.1, C35.1, J4.2, J6.2, J9.3, J10.1, J11.1, J11.7, J12.4, R3.2, R4.1, R21.1, U1.2 (3V3), U5.5 (VOUT)
/BUZZER: Q3.1 (G), R13.1, U1.39 (IO1)
/CC_CS: J6.4, U1.5 (IO5)
/CC_GD00: J6.3, U1.8 (IO15)
/CC_GD02: J6.8, U1.35 (IO42)
/GPS_RX: J12.3, U1.17 (IO9)
/GPS_TX: J12.2, U1.11 (IO18)
/I2C_SCL: J9.1, U1.18 (IO10)
/I2C_SDA: J9.2, U1.21 (IO13)
/IR_RX: U1.38 (IO2), U2.1 (OUT)
/IR_TX: R5.2, U1.34 (IO41)
/JOY_DOWN: SW1.2, U1.19 (IO11)
/JOY_L: SW1.3, U1.31 (IO38)
/JOY_OK: SW1.5, U1.33 (IO40)
/JOY_R: SW1.4, U1.32 (IO39)
/JOY_UP: SW1.1, U1.20 (IO12)
/NRF_CE: J4.3, U1.7 (IO7)
/NRF_CSN: J4.4, U1.6 (IO6)
/NRF_IRQ: J4.8, U1.4 (IO4)
/SD_CS: J10.2, U1.25 (IO48)
/SPI_MISO: J4.7, J6.7, J10.5, U1.22 (IO14)
/SPI_MOSI: J4.6, J6.6, J10.3, J11.5, U1.24 (IO47)
/SPI_SCK: J4.5, J6.5, J10.4, J11.6, U1.23 (IO21)
/TFT_CS: J11.2, U1.9 (IO16)
/TFT_DC: J11.3, U1.10 (IO17)
BAT_SENSE: R12.2, R19.1, U1.12 (IO8)
EN: C10.1, J11.4, R4.2, Reset2.2, U1.3 (EN)
GND: C1.2, C2.2, C3.1, C4.2, C5.2, C6.2, C7.2, C8.2, C9.2, C10.2, C11.2, C12.2, C13.2, C20.2, C22.2, C35.2, C36.2, Flash1.1, GND1.1, J1.A1 (GND), J1.A12 (GND), J1.B1 (GND), J1.B12 (GND), J1.S1 (SHIELD), J2.1, J4.1, J6.1, J9.4, J10.6, J11.8, J12.1, Q2.2 (S), Q3.2 (S), R1.1, R11.1, R11.2, R13.2, R14.1, R17.1, R19.2, R20.1, Reset2.1, SW1.6 (Common), U1.1 (GND), U1.40 (GND), U1.41 (GND), U2.2 (GND), U3.2 (V_{SS}), U4.2 (GND), U5.2 (GND)
IO0: Flash1.2, R21.2, U1.27 (IO0)
unnamed: BZ1.2 (-), Q3.3 (D)
unnamed: D1.1 (K), R15.2
unnamed: D7.1 (K), R8.1
unnamed: D8.1 (K), R9.1
unnamed: J1.A5 (CC1), R14.2
unnamed: J1.B5 (CC2), R17.2
unnamed: Q2.3 (D), R8.2, R9.2
unnamed: Q2.1 (G), R5.1
unnamed: C3.2, R3.1, U2.3 (Vs)
unnamed: R1.2, U3.5 (PROG)
unnamed: R15.1, U3.1 (STAT)
USB_D+: J1.A6 (D+), J1.B6 (D+), R18.1, R18.2, U1.14 (USB_D+), U4.1 (I/O1), U4.6 (I/O1)
USB_D-: J1.A7 (D-), J1.B7 (D-), R2.1, R2.2, U1.13 (USB_D-), U4.3 (I/O2), U4.4 (I/O2)
VBAT: C2.1, C8.1, J2.2, Q1.3 (D), R12.1, U3.3 (V_{BAT})
VSYS: C7.1, C9.1, C11.1, C12.1, C13.1, D4.1 (K), D7.2 (A), D8.2 (A), Q1.2 (S), U5.1 (VIN), U5.3 (CE)

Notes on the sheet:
BATTERY CHARGER
VOLTAGE REGULATOR
BOOT
RESET
MODULES
LDO SWITCH
MCU
IR TRANSMITTER
IR RECEIVER
USB-C

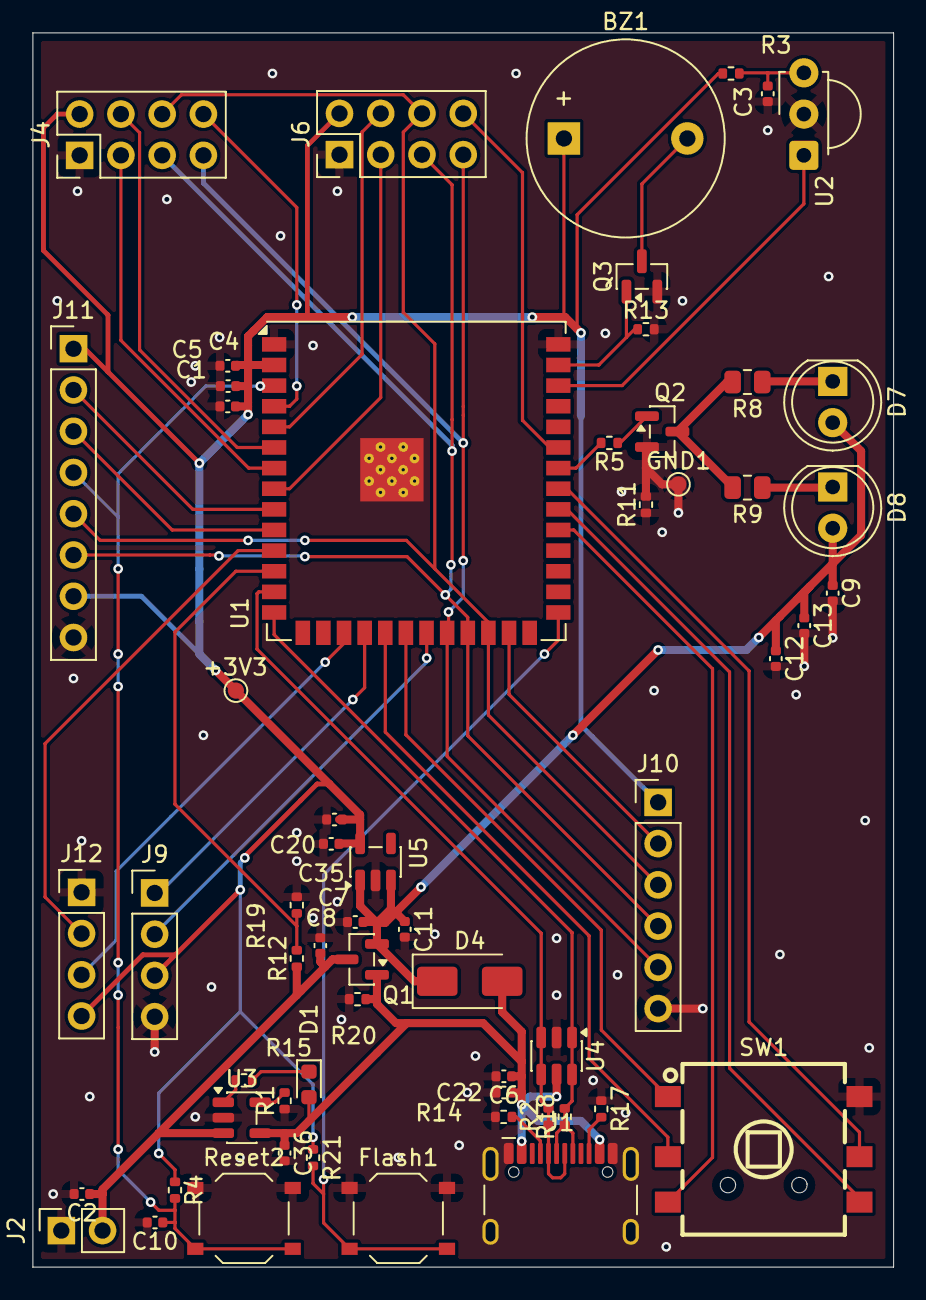
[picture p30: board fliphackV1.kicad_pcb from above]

Board: 2 copper layers, 53.0 x 76.0 mm, 60 parts (0 on the bottom side), 45 nets.

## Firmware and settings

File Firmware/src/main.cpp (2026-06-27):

#include <Arduino.h>
#include <TFT_eSPI.h> 
#include <lvgl.h>
#include "ui.h" 
#include "driver/gpio.h" 
#include <SPI.h>
#include <SD.h>
#include <IRrecv.h>   
#include <IRutils.h>  
#include <RadioLib.h> 
#include <TinyGPS++.h> 
#include <sys/time.h> 
#include <WiFi.h> 
#include <esp_wifi.h> 
#include <FS.h>
#include <Wire.h>
#include <Adafruit_PN532.h>

#define JOY_UP    12  
#define JOY_LEFT  11 
#define JOY_DOWN  38  
#define JOY_RIGHT 40  
#define JOY_OK    39  

#define GPS_RX_PIN 18 
#define GPS_TX_PIN 9
#define BUZZER_PIN 1 

#define SPI_SCK_PIN  21
#define SPI_MISO_PIN 14
#define SPI_MOSI_PIN 47

#define SD_CS_PIN    48
#define TFT_CS_PIN   16

#define CC_CS_PIN    5 
#define CC_GDO0_PIN  15
#define CC_GDO2_PIN  42

#define NRF_CSN_PIN  6 
#define NRF_CE_PIN   7  
#define NRF_IRQ_PIN  4  

#define IR_RX_PIN    2

#define PN_532_SCL_PIN 10
#define PN_532_SDA_PIN 13

Adafruit_PN532 nfc(PN_532_SDA_PIN, PN_532_SCL_PIN);

TFT_eSPI tft = TFT_eSPI(); 

CC1101 cc1101 = new Module(CC_CS_PIN, CC_GDO0_PIN, RADIOLIB_NC, CC_GDO2_PIN);
nRF24 nrf24 = new Module(NRF_CSN_PIN, NRF_IRQ_PIN, NRF_CE_PIN);

TinyGPSPlus gps;
bool nmea_paused = false;
String nmea_buffer = ""; 

bool BUZZER_ON = true;

bool     pn532_ok              = false;
bool     nfc_scan_active       = false;
uint8_t  nfc_last_uid[7]       = {0};
uint8_t  nfc_last_uid_len      = 0;
uint8_t  nfc_last_sak          = 0;
String   nfc_last_uid_str      = "";
String   nfc_last_type_str     = "";
bool     nfc_tag_found         = false;

float current_cc_freq = 433.92;
bool cc1101_ok = false;
int cc1101_last_state = RADIOLIB_ERR_NONE;
bool cc1101_receiving = false;
uint32_t cc1101_last_retry_ms = 0;

bool sd_card_ok = false;

String fliphack_target_ssid = "NONE";
String fliphack_target_bssid = "00:00:00:00:00:00"; 
uint8_t target_mac[6] = {0xFF, 0xFF, 0xFF, 0xFF, 0xFF, 0xFF}; 
int fliphack_target_channel = 0;
int fliphack_target_rssi = 0;
String fliphack_target_enc = "OPEN";

int wifi_scan_status = 0;

bool deauth_running = false;
uint32_t deauth_packets_sent = 0;
uint32_t deauth_start_time = 0;

struct pcap_file_header {
    uint32_t magic_number  = 0xa1b2c3d4;
    uint16_t version_major = 2;
    uint16_t version_minor = 4;
    int32_t  thiszone      = 0;
    uint32_t sigfigs       = 0;
    uint32_t snaplen       = 65535;
    uint32_t network       = 105; 
};

struct pcap_record_header {
    uint32_t ts_sec;
    uint32_t ts_usec;
    uint32_t incl_len;
    uint32_t orig_len;
};

bool     handshake_capture_active = false;
bool     handshake_captured       = false;
uint8_t  handshake_count          = 0;
File     pcap_file;
bool     pcap_file_open           = false;
String   pcap_filename            = "";

void IRAM_ATTR wifi_sniffer_cb(void* buf, wifi_promiscuous_pkt_type_t type) {
    if (!handshake_capture_active) return;
    if (type != WIFI_PKT_DATA && type != WIFI_PKT_MGMT) return;

    const wifi_promiscuous_pkt_t* pkt = (wifi_promiscuous_pkt_t*)buf;
    const uint8_t* data   = pkt->payload;
    uint16_t       len    = pkt->rx_ctrl.sig_len;

    if (len < 24) return;

    bool match = false;
    for (int addr_offset : {4, 10, 16}) {
        if (memcmp(data + addr_offset, target_mac, 6) == 0) { match = true; break; }
    }
    if (!match) return;

    uint8_t frame_type = (data[0] & 0x0C) >> 2;
    if (frame_type != 2) return;

    uint8_t fc_subtype = (data[0] & 0xF0) >> 4;
    int hdr_len = 24;
    if (fc_subtype & 0x08) hdr_len = 26;

    if (len < (uint16_t)(hdr_len + 8)) return;

    const uint8_t* llc = data + hdr_len;
    if (llc[0] == 0xAA && llc[1] == 0xAA && llc[6] == 0x88 && llc[7] == 0x8E) {
        if (!pcap_file_open) return;

        struct timeval tv;
        gettimeofday(&tv, NULL);

        pcap_record_header rec;
        rec.ts_sec  = tv.tv_sec;
        rec.ts_usec = tv.tv_usec;
        rec.incl_len = len;
        rec.orig_len = len;

        pcap_file.write((uint8_t*)&rec, sizeof(rec));
        pcap_file.write(data, len);
        pcap_file.flush();

        handshake_count++;
        handshake_captured = (handshake_count >= 4);
    }
}

void start_handshake_capture() {
    if (pcap_file_open) return;

    handshake_count    = 0;
    handshake_captured = false;

    char fname[40];
    sprintf(fname, "/handshakes/%s.pcap",
            fliphack_target_ssid.length() > 0 ? fliphack_target_ssid.c_str() : "hidden");
    pcap_filename = String(fname);

    if (!SD.exists("/handshakes")) SD.mkdir("/handshakes");

    pcap_file = SD.open(pcap_filename, FILE_WRITE);
    if (!pcap_file) return;

    pcap_file_header fhdr;
    pcap_file.write((uint8_t*)&fhdr, sizeof(fhdr));
    pcap_file.flush();
    pcap_file_open = true;

    esp_wifi_set_promiscuous_rx_cb(wifi_sniffer_cb);
    handshake_capture_active = true;
}

void stop_handshake_capture() {
    handshake_capture_active = false;
    esp_wifi_set_promiscuous_rx_cb(NULL);
    if (pcap_file_open) {
        pcap_file.close();
        pcap_file_open = false;
    }
}

static const char* nfcTagTypeName(uint8_t sak) {
    if (sak == 0x08 || sak == 0x00) return "MIFARE Classic 1K";
    if (sak == 0x18)                return "MIFARE Classic 4K";
    if (sak == 0x20)                return "MIFARE DESFire";
    if (sak == 0x60)                return "MIFARE Plus";
    if (sak == 0x28)                return "JCOP Java Card";
    return "ISO14443-A";
}

static String nfcUidToString(uint8_t* uid, uint8_t len) {
    String s = "";
    for (uint8_t i = 0; i < len; i++) {
        if (uid[i] < 0x10) s += "0";
        s += String(uid[i], HEX);
        if (i < len - 1) s += ":";
    }
    s.toUpperCase();
    return s;
}

static void nfcSaveTagToSD() {
    if (!sd_card_ok || !nfc_tag_found) return;
    if (!SD.exists("/nfc_tags")) SD.mkdir("/nfc_tags");

    String uid_clean = nfc_last_uid_str;
    uid_clean.replace(":", "");

    String type_short = nfc_last_type_str;
    type_short.replace(" ", "_"); 

    String fname = "/nfc_tags/" + uid_clean + "_" + type_short + ".txt";

    File f = SD.open(fname, FILE_WRITE);
    if (!f) {
        Serial.println("Chyba: Nelze otevrit soubor pro zapis!");
        return;
    }

    f.printf("--- TAG INFO ---\n");
    f.printf("UID: %s\n", nfc_last_uid_str.c_str());
    f.printf("SAK: 0x%02X\n", nfc_last_sak);
    f.printf("Type: %s\n", nfc_last_type_str.c_str());
    f.printf("Timestamp: %lu\n", millis()); 
    f.close();
    
    Serial.println("Ulozeno do: " + fname);
}

static void nfcResetGui() {
    if (ui_ReadTagUID1)   lv_label_set_text(ui_ReadTagUID1,   "--:--:--:--");
    if (ui_ReadTagSAK)    lv_label_set_text(ui_ReadTagSAK,    "0x--");
    if (ui_ReadTagType)   lv_label_set_text(ui_ReadTagType,   "---");
    if (ui_ReadTagStatus) {
        lv_label_set_text(ui_ReadTagStatus, "APPROACH CARD");
        lv_obj_set_style_text_color(ui_ReadTagStatus,
            lv_color_hex(0xFFB200), LV_PART_MAIN | LV_STATE_DEFAULT);
    }
    nfc_tag_found = false;
}

uint8_t deauthPacket[26] = {
    0xC0, 0x00, 0x00, 0x00, 
    0xFF, 0xFF, 0xFF, 0xFF, 0xFF, 0xFF, 
    0x00, 0x00, 0x00, 0x00, 0x00, 0x00, 
    0x00, 0x00, 0x00, 0x00, 0x00, 0x00, 
    0x00, 0x00, 
    0x07, 0x00 
};

static const uint16_t screenWidth  = 280;
static const uint16_t screenHeight = 240;
static lv_disp_draw_buf_t draw_buf;
static lv_color_t *buf; 
bool isBooted = false;

lv_group_t * g; 
lv_obj_t * current_screen = NULL;

IRrecv irrecv(IR_RX_PIN);
decode_results results;

uint64_t learn_signal_value = 0;
uint16_t learn_signal_bits = 0;
decode_type_t learn_signal_protocol = UNKNOWN;
uint32_t learn_signal_address = 0;
uint32_t learn_signal_command = 0;
bool learn_signal_has_data = false;

static void learnSignalResetData() {
    learn_signal_value = 0;
    learn_signal_bits = 0;
    learn_signal_protocol = UNKNOWN;
    learn_signal_address = 0;
    learn_signal_command = 0;
    learn_signal_has_data = false;
}

static void learnSignalSetWaitingGui() {
    if (!ui_LearnSignalIRSTATUS || !ui_LearnSignalProtocol ||
        !ui_LearnSignalAdress || !ui_LearnSignalCommand) {
        return;
    }

    lv_label_set_text(ui_LearnSignalIRSTATUS, "Waiting for IR signal...");
    lv_obj_set_style_text_color(ui_LearnSignalIRSTATUS, lv_color_hex(0xFFFFFF),
                                LV_PART_MAIN | LV_STATE_DEFAULT);
    lv_label_set_text(ui_LearnSignalProtocol, "----");
    lv_label_set_text(ui_LearnSignalAdress, "0x00");
    lv_label_set_text(ui_LearnSignalCommand, "0x00");
}

static void learnSignalUpdateGui(const decode_results *ir_results) {
    if (!ir_results) return;

    learn_signal_value = ir_results->value;
    learn_signal_bits = ir_results->bits;
    learn_signal_protocol = ir_results->decode_type;
    learn_signal_address = ir_results->address;
    learn_signal_command = ir_results->command;
    learn_signal_has_data = true;

    if (!ui_LearnSignalIRSTATUS || !ui_LearnSignalProtocol ||
        !ui_LearnSignalAdress || !ui_LearnSignalCommand) {
        return;
    }

    String protocol = typeToString(ir_results->decode_type);
    char address_buf[16];
    char command_buf[24];

    lv_label_set_text_fmt(ui_LearnSignalIRSTATUS, "IR signal learned (%u bits)",
                          ir_results->bits);
    lv_obj_set_style_text_color(ui_LearnSignalIRSTATUS, lv_color_hex(0x00FF48),
                                LV_PART_MAIN | LV_STATE_DEFAULT);
    lv_label_set_text(ui_LearnSignalProtocol, protocol.c_str());

    if (ir_results->decode_type == UNKNOWN) {
        snprintf(address_buf, sizeof(address_buf), "RAW");
        snprintf(command_buf, sizeof(command_buf), "0x%llX",
                 (unsigned long long)ir_results->value);
    } else {
        snprintf(address_buf, sizeof(address_buf), "0x%04lX",
                 (unsigned long)ir_results->address);
        snprintf(command_buf, sizeof(command_buf), "0x%04lX",
                 (unsigned long)ir_results->command);
    }

    lv_label_set_text(ui_LearnSignalAdress, address_buf);
    lv_label_set_text(ui_LearnSignalCommand, command_buf);
}

void playTone(int freq, int duration) {
   tone(BUZZER_PIN, freq, duration);
   delay(duration + 30); 
}


static void learnSignalHandleRescanButton() {
    static bool rescan_was_pressed = false;
    if (!ui_LearnSignalRESCAN) return;

    bool rescan_is_pressed = lv_obj_get_state(ui_LearnSignalRESCAN) & LV_STATE_PRESSED;
    if (rescan_is_pressed && !rescan_was_pressed) {
        learnSignalResetData();
        learnSignalSetWaitingGui();
        irrecv.resume();
    }

    rescan_was_pressed = rescan_is_pressed;
}

static bool cc1101BeginRadio() {
    digitalWrite(TFT_CS_PIN, HIGH);
    digitalWrite(SD_CS_PIN, HIGH);
    digitalWrite(NRF_CSN_PIN, HIGH);

    cc1101_receiving = false;
    cc1101_last_state = cc1101.begin(current_cc_freq, 4.8, 48.0, 26.0, 10, 32);
    cc1101_ok = (cc1101_last_state == RADIOLIB_ERR_NONE);

    if (cc1101_ok) {
        cc1101.standby();
    }

    return cc1101_ok;
}

static bool cc1101SetReceiveMode(bool enabled) {
    if (!cc1101_ok) return false;

    if (enabled && !cc1101_receiving) {
        cc1101_last_state = cc1101.startReceive();
        cc1101_receiving = (cc1101_last_state == RADIOLIB_ERR_NONE);
        return cc1101_receiving;
    }

    if (!enabled && cc1101_receiving) {
        cc1101_last_state = cc1101.standby();
        cc1101_receiving = false;
    }

    return true;
}

static const char *sdCardTypeName(uint8_t card_type) {
    switch (card_type) {
        case CARD_MMC: return "MMC";
        case CARD_SD: return "SDSC";
        case CARD_SDHC: return "SDHC";
        default: return "NONE";
    }
}

static void updateMainMenuGui() {
    if (ui_time) {
        struct timeval tv;
        gettimeofday(&tv, NULL);
        struct tm *timeinfo = localtime(&tv.tv_sec);
        if (timeinfo && timeinfo->tm_year >= 120) {
            lv_label_set_text_fmt(ui_time, "%02d:%02d", timeinfo->tm_hour, timeinfo->tm_min);
        } else {
            uint32_t uptime_s = millis() / 1000;
            lv_label_set_text_fmt(ui_time, "%02lu:%02lu", uptime_s / 60, uptime_s % 60);
        }
    }

    if (ui_SDCONNECTION) {
        bool has_sd = sd_card_ok && SD.cardType() != CARD_NONE;
        lv_label_set_text(ui_SDCONNECTION, has_sd ? "SD" : "NO SD");
        lv_obj_set_style_text_color(ui_SDCONNECTION,
                                    has_sd ? lv_color_hex(0x32FF00) : lv_color_hex(0xFF3030),
                                    LV_PART_MAIN | LV_STATE_DEFAULT);
    }

    if (ui_FirmwareProject) {
        lv_label_set_text(ui_FirmwareProject, "Fliphack v1.0");
    }

    if (ui_battery) {
        lv_bar_set_value(ui_battery, 100, LV_ANIM_OFF);
    }
}

static void updateDeviceInfoGui() {
    if (ui_DeviceInfoFirmware) lv_label_set_text(ui_DeviceInfoFirmware, "Fliphack v1.0");
    if (ui_DeviceInfoTemp) lv_label_set_text_fmt(ui_DeviceInfoTemp, "%.1f C", temperatureRead());
    if (ui_DeviceInfoBattery) lv_label_set_text(ui_DeviceInfoBattery, "USB/EXT");

    if (ui_DeviceInfoPSRAMFREE) {
        uint32_t free_kb = ESP.getFreePsram() / 1024;
        uint32_t total_kb = ESP.getPsramSize() / 1024;
        lv_label_set_text_fmt(ui_DeviceInfoPSRAMFREE, "%lu/%lu KB",
                              (unsigned long)free_kb, (unsigned long)total_kb);
    }
}
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
void loop() {
    if (!isBooted) {
        buf = (lv_color_t*)heap_caps_malloc(screenWidth * 40 * sizeof(lv_color_t), MALLOC_CAP_SPIRAM);
        if (buf == NULL) while(1) delay(100);

        tft.init(); tft.setRotation(1); tft.setSwapBytes(false); tft.invertDisplay(true); tft.fillScreen(TFT_BLACK);
        lv_init(); lv_disp_draw_buf_init(&draw_buf, buf, NULL, screenWidth * 40);
        static lv_disp_drv_t disp_drv;
        lv_disp_drv_init(&disp_drv);
        disp_drv.hor_res = screenWidth; disp_drv.ver_res = screenHeight; disp_drv.flush_cb = my_disp_flush; disp_drv.draw_buf = &draw_buf;
        lv_disp_drv_register(&disp_drv);

        pinMode(JOY_UP, INPUT_PULLUP); pinMode(JOY_DOWN, INPUT_PULLUP); pinMode(JOY_LEFT, INPUT_PULLUP);
        pinMode(JOY_RIGHT, INPUT_PULLUP); pinMode(JOY_OK, INPUT_PULLUP);

        gpio_reset_pin(GPIO_NUM_39); gpio_set_direction(GPIO_NUM_39, GPIO_MODE_INPUT); gpio_set_pull_mode(GPIO_NUM_39, GPIO_PULLUP_ONLY);
        gpio_reset_pin(GPIO_NUM_40); gpio_set_direction(GPIO_NUM_40, GPIO_MODE_INPUT); gpio_set_pull_mode(GPIO_NUM_40, GPIO_PULLUP_ONLY);

        static lv_indev_drv_t indev_drv; lv_indev_drv_init(&indev_drv); indev_drv.type = LV_INDEV_TYPE_KEYPAD; indev_drv.read_cb = my_keypad_read; lv_indev_t * my_indev = lv_indev_drv_register(&indev_drv);
        g = lv_group_create(); lv_group_set_default(g); lv_indev_set_group(my_indev, g);

        ui_init(); 
        current_screen = lv_scr_act(); load_group_for_screen(current_screen);
        isBooted = true;
        if (BUZZER_ON){
            pinMode(BUZZER_PIN, OUTPUT);
            playTone(1000, 150); 
        }
        Serial.println("====== FLIPHACK O.S. PRIPRAVEN ======");
        
        
    } else {
        static uint32_t last_tick = millis();
        lv_tick_inc(millis() - last_tick);
        last_tick = millis();
        lv_timer_handler(); 

        if (current_screen != lv_scr_act()) {
            current_screen = lv_scr_act(); 
            load_group_for_screen(current_screen);
            
            static bool initial_dummy_cleared = false;
            if (current_screen == ui_ScanAPs && !initial_dummy_cleared) {
                lv_obj_clean(ui_WIFINetworks);
                initial_dummy_cleared = true;
            }
            
            if (current_screen == ui_WiFiMenu && ui_WIFIMenuTarget) lv_label_set_text(ui_WIFIMenuTarget, fliphack_target_ssid.c_str());
            if (current_screen == ui_ScanAPs && ui_WIFIMenuTarget1) lv_label_set_text(ui_WIFIMenuTarget1, fliphack_target_ssid.c_str());
            if (current_screen == ui_DeauthAttack && ui_DeauthAttackTarget) lv_label_set_text(ui_DeauthAttackTarget, fliphack_target_ssid.c_str());

            if (current_screen != ui_DeauthAttack && deauth_running) {
                deauth_running = false;
                stop_handshake_capture();
                WiFi.mode(WIFI_STA); 
            }

            if (current_screen == ui_SpectrumAnalyzer) {
                nrf24.startReceive(); 
            } else {
                nrf24.standby(); 
            }

            cc1101SetReceiveMode(current_screen == ui_FREQAnalyzer);

            if (current_screen == ui_WIFIDetails) {
                if (ui_WIFIMenuTarget2) lv_label_set_text(ui_WIFIMenuTarget2, fliphack_target_ssid.c_str());
                if (ui_SSIDDetails) lv_label_set_text(ui_SSIDDetails, fliphack_target_ssid.c_str());
                if (ui_BSSIDDetails) lv_label_set_text(ui_BSSIDDetails, fliphack_target_bssid.c_str());
                if (ui_ChannelDetails) lv_label_set_text_fmt(ui_ChannelDetails, "%d", fliphack_target_channel);
                if (ui_RSSIDetails) lv_label_set_text_fmt(ui_RSSIDetails, "%d dBm", fliphack_target_rssi);
                if (ui_EncryptionDetails) lv_label_set_text(ui_EncryptionDetails, fliphack_target_enc.c_str());
                
                if (ui_BeaconsDetails) lv_label_set_text(ui_BeaconsDetails, "N/A");
                if (ui_WPSDetails) lv_label_set_text(ui_WPSDetails, "N/A");
                if (ui_HiddenDetails) lv_label_set_text(ui_HiddenDetails, fliphack_target_ssid.length() == 0 ? "YES" : "NO");
                if (ui_ClientsDetails) lv_label_set_text(ui_ClientsDetails, "Skryto");
                if (ui_DATAPKTSDetails) lv_label_set_text(ui_DATAPKTSDetails, "0");
            }

            if (current_screen == ui_LearnSignal) {
                learnSignalResetData();
                learnSignalSetWaitingGui();
                irrecv.enableIRIn();
            }

            if (current_screen == ui_ReadTag) {
               nfcResetGui();
               nfc_scan_active = true;
               if (!pn532_ok) {
                   if (ui_ReadTagStatus) {
                       lv_label_set_text(ui_ReadTagStatus, "PN532 NOT FOUND!");
                       lv_obj_set_style_text_color(ui_ReadTagStatus,
                       lv_color_hex(0xFF3030), LV_PART_MAIN | LV_STATE_DEFAULT);
                    }
                }
            } else {
               nfc_scan_active = false;
            }

            if (current_screen == ui_MainMenu) updateMainMenuGui();
            if (current_screen == ui_DeviceInfo) updateDeviceInfoGui();
            if (current_screen == ui_StorageInfo) updateStorageInfoGui();
        }

        if (current_screen == ui_RadioConfig) {
            static bool apply_btn_was_pressed = false;
            bool apply_btn_is_pressed = lv_obj_get_state(ui_RadioConfigAPPLY) & LV_STATE_PRESSED;

            if (apply_btn_is_pressed && !apply_btn_was_pressed) {
                uint16_t freq_idx = lv_dropdown_get_selected(ui_RadioConfigFREQ);
                
                if (freq_idx == 0) current_cc_freq = 315.00;
                else if (freq_idx == 1) current_cc_freq = 433.92;
                else if (freq_idx == 2) current_cc_freq = 868.00;

                cc1101SetReceiveMode(false);
                if (!cc1101_ok) cc1101BeginRadio();

                if (cc1101_ok) {
                    cc1101_last_state = cc1101.setFrequency(current_cc_freq);
                    if (cc1101_last_state == RADIOLIB_ERR_NONE) {
                        lv_label_set_text(ui_Label311, "OK!");
                        lv_obj_set_style_text_color(ui_Label311, lv_color_hex(0x00FF48),
                                                    LV_PART_MAIN | LV_STATE_DEFAULT);
                    } else {
                        lv_label_set_text_fmt(ui_Label311, "ERR %d", cc1101_last_state);
                        lv_obj_set_style_text_color(ui_Label311, lv_color_hex(0xFF3030),
                                                    LV_PART_MAIN | LV_STATE_DEFAULT);
                    }
                } else {
                    lv_label_set_text_fmt(ui_Label311, "CC ERR %d", cc1101_last_state);
                    lv_obj_set_style_text_color(ui_Label311, lv_color_hex(0xFF3030),
                                                LV_PART_MAIN | LV_STATE_DEFAULT);
                }
            } else if (!apply_btn_is_pressed && apply_btn_was_pressed) {
                lv_label_set_text(ui_Label311, "APPLY");
            }
            apply_btn_was_pressed = apply_btn_is_pressed;
        }

        else if (current_screen == ui_WiFiMenu || current_screen == ui_ScanAPs || current_screen == ui_WIFIDetails ||
                 current_screen == ui_DeauthAttack || current_screen == ui_BeaconSpam || current_screen == ui_EvilTwin) {
            
            static bool scan_btn_was_pressed = false;

            if (current_screen == ui_WiFiMenu) {
                bool trigger_scan_is_pressed = lv_obj_get_state(ui_ScanAPsSelect) & LV_STATE_PRESSED;
                if (trigger_scan_is_pressed && !scan_btn_was_pressed && wifi_scan_status == 0) {
                    WiFi.scanDelete(); 
                    WiFi.scanNetworks(true); 
                    wifi_scan_status = 1;
                }
                scan_btn_was_pressed = trigger_scan_is_pressed;
            }
            
            if (current_screen == ui_ScanAPs) {
                bool scan_btn_is_pressed = lv_obj_get_state(ui_SCANAPsButton) & LV_STATE_PRESSED;
                if (scan_btn_is_pressed && !scan_btn_was_pressed && wifi_scan_status == 0) {
                    lv_obj_clean(ui_WIFINetworks);
                    lv_obj_t * loading = lv_label_create(ui_WIFINetworks);
                    lv_label_set_text(loading, "Skenuji site...\n(Plynule na pozadi)");
                    lv_obj_set_style_text_color(loading, lv_color_hex(0xFFFFFF), 0);
                    
                    WiFi.scanDelete(); 
                    WiFi.scanNetworks(true); 
                    wifi_scan_status = 1;
                }
                scan_btn_was_pressed = scan_btn_is_pressed;
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

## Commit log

2026-03-02 Add Bill of Materials to README
    Added a Bill of Materials section detailing components and quantities for the project.
2026-03-02 Revise README with updated BOM and assembly details
    Updated the Bill of Materials with new components and specifications. Added a new section for Mechanical & Assembly.
2026-03-03 Add LiPo Battery specifications to README
2026-03-06 Enhance BOM with assembly notes for components
    Updated the Bill of Materials to include assembly notes for components.
2026-03-07 Add assembly preview image to README
2026-03-07 Add more assembly preview images
    Added additional assembly preview images to the README.
2026-03-07 Add assembly preview image to README
    Added an additional assembly preview image to the README.
2026-03-07 Update README with new images and PCB render
    Added additional assembly preview images and a 3D PCB render to the README.
2026-03-07 Update PCB 3D image in README
2026-03-07 Rename Snímek obrazovky 2026-03-02 201856.png to pcb3d1.png
2026-03-07 Rename Snímek obrazovky 2026-03-04 182400.png to pcb3d2.png
2026-03-07 Rename Snímek obrazovky 2026-03-07 082603.png to pcb3d3.png
2026-03-07 Rename Snímek obrazovky 2026-03-07 082728.png to pcb3d4.png
2026-03-07 Rename Snímek obrazovky 2026-03-07 082822.png to pcb3d5.png
2026-03-07 Rename Snímek obrazovky 2026-03-07 082907.png to pcb3d6.png
2026-03-07 Rename Snímek obrazovky 2026-03-07 083031.png to pcb3d7.png
2026-03-07 Update and rename fliphackV1.csv to BOM.csv
    [BOM.csv]
2026-03-07 Update BOM with detailed ESP32-S3-WROOM-1U info
    Expanded description for ESP32-S3-WROOM-1U component regarding sourcing and pricing.
2026-03-07 Update PCB images in README
    Removed an outdated PCB 3D image and updated PCB 2D image reference.
2026-03-07 Fix image path for PCB 2D in README
2026-03-07 Update quantity of ESP32-S3-WROOM-1U to 5
2026-03-07 Update README with 2.4GHz Antenna details
    Added details for 2.4GHz Antenna with pigtail to components list.
2026-03-15 Remove GND1 entry from BOM.csv
    Removed GND1 entry from BOM.
    [BOM.csv]
2026-03-19 Enhance BOM entry for ESP32-S3-WROOM-1U
    Updated the description for ESP32-S3-WROOM-1U with additional LCSC part number.
2026-03-19 Fix LCSC part number formatting in BOM section
